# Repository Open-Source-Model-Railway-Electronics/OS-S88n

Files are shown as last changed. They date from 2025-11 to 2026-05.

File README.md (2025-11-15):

# OS-S88n-CS

The OS-S88n modules provide feedback functionality for DCC model railroads using the standardized S88n protocol. These modules allow real-time monitoring of block occupancy and layout events by sending data to your command station or PC-based software.

Models:
    • OS-S88n GND — Standard input module using ground-contact detection  
    • OS-S88n CS — current-sensing module  
    • OS-S88n OPTO — Opto-isolated module for clean, noise-free sensor inputs  

All versions include:
    • Daisy-chainable S88n connectors (RJ-45)  
    • Screw terminals for simple input wiring  
    • Compatibility with all major command stations and software (iTrain, Rocrail, Windigipet, etc.)

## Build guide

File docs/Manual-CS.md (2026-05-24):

> 🌐 &nbsp; [🇬🇧 EN](Manual-EN.md) &nbsp;|&nbsp; [🇩🇪 DE](Manual-DE.md) &nbsp;|&nbsp; [🇫🇷 FR](Manual-FR.md) &nbsp;|&nbsp; [🇳🇱 NL](Manual-NL.md) &nbsp;|&nbsp; [🇪🇸 ES](Manual-ES.md) &nbsp;|&nbsp; [🇮🇹 IT](Manual-IT.md) &nbsp;|&nbsp; [🇵🇱 PL](Manual-PL.md) &nbsp;|&nbsp; 🇨🇿 CS &nbsp;|&nbsp; [🇩🇰 DA](Manual-DA.md) &nbsp;|&nbsp; [🇳🇴 NO](Manual-NO.md) &nbsp;|&nbsp; [🇸🇪 SV](Manual-SV.md) &nbsp;|&nbsp; [🇭🇺 HU](Manual-HU.md) &nbsp;|&nbsp; [🇵🇹 PT](Manual-PT.md)

# Manuál zpětnovazebních modulů OS-S88n

**Podporuje: OS-S88n GND · OS-S88n CS · OS-S88n OPTO**

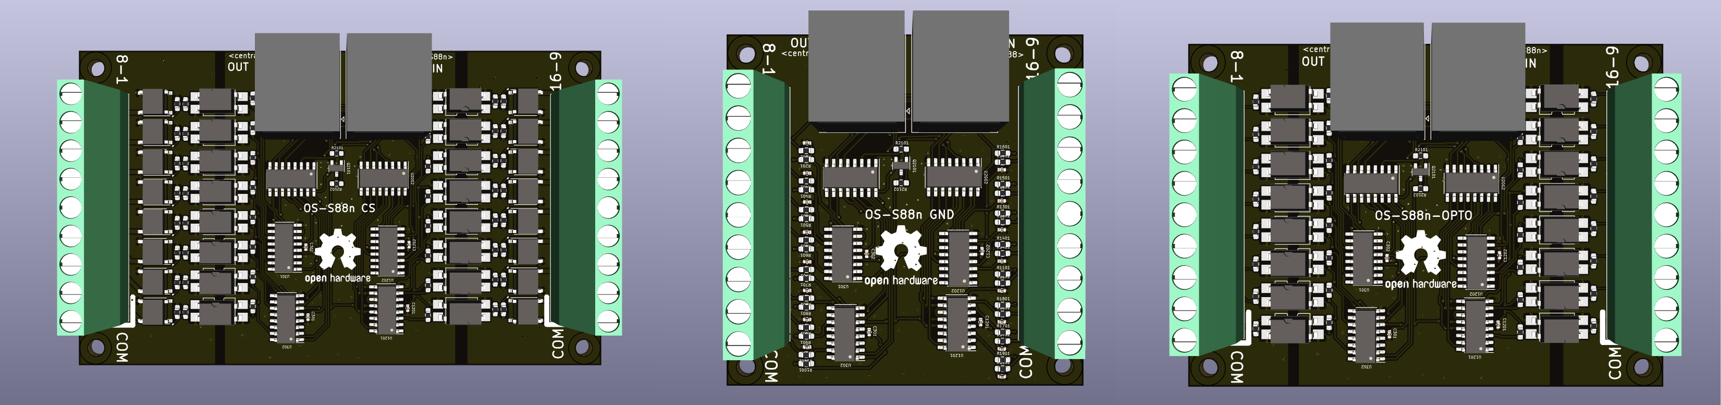
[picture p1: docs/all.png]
Všechny tři varianty modulu OS-S88n


*Zleva doprava: OS-S88n CS, OS-S88n GND, OS-S88n OPTO*

---

## Úvod

Moduly OS-S88n zajišťují zpětnovazební funkci pro DCC modelové železnice pomocí standardizovaného protokolu S88n. Tyto moduly umožňují sledování obsazení bloků a událostí na kolejišti v reálném čase a odesílají data do vaší příkazové stanice nebo počítačového řídicího softwaru.

K dispozici jsou tři varianty pro různé detekční potřeby:

- **OS-S88n GND** — detekce uzemnění, vhodná pro kolejiště s 3 kolejnicemi (ve stylu Märklin)
- **OS-S88n CS** — detekce proudu, vhodná pro digitální kolejiště se 2 i 3 kolejnicemi
- **OS-S88n OPTO** — opticky izolované digitální vstupy pro použití s externími senzory jako jsou IR detektory nebo Hallovy senzory

Všechny varianty obsahují:

- Řetězitelné S88n konektory (RJ-45)
- Šroubové svorky pro všechna připojení senzorů
- Kompatibilita se všemi hlavními příkazovými stanicemi a softwarem (iTrain, Rocrail, Windigipet atd.)

---

## Varianty modulů

### OS-S88n GND — Detekce uzemnění

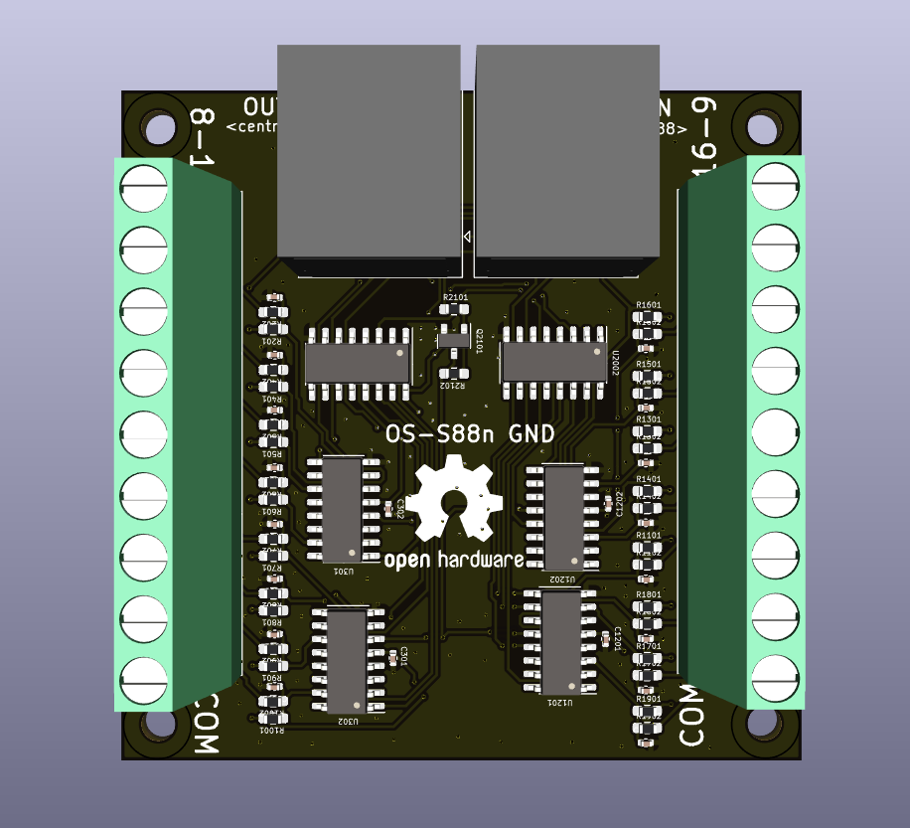
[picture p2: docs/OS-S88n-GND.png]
Deska OS-S88n GND


Modul GND má 16 vstupů, které se aktivují při přivedení vstupu na zem. Kompatibilní senzory a detekční metody zahrnují:

- Reedovy spínače
- Tlačítka
- Kovová kolová soustrojí přemosťující koleje na kolejišti se 3 kolejnicemi (ve stylu Märklin)

⚠️ **Důležité — kolejiště se 3 kolejnicemi:** Při použití modulu GND na kolejišti se 3 kolejnicemi musí vaše příkazová stanice a všechny zesilovače **být** typu se společnou zemí. Pokud vaše příkazová stanice používá H-můstkový výstup, použití modulu GND **poškodí vaši příkazovou stanici**. V takovém případě použijte místo toho variantu OPTO.

---

### OS-S88n CS — Měření proudu

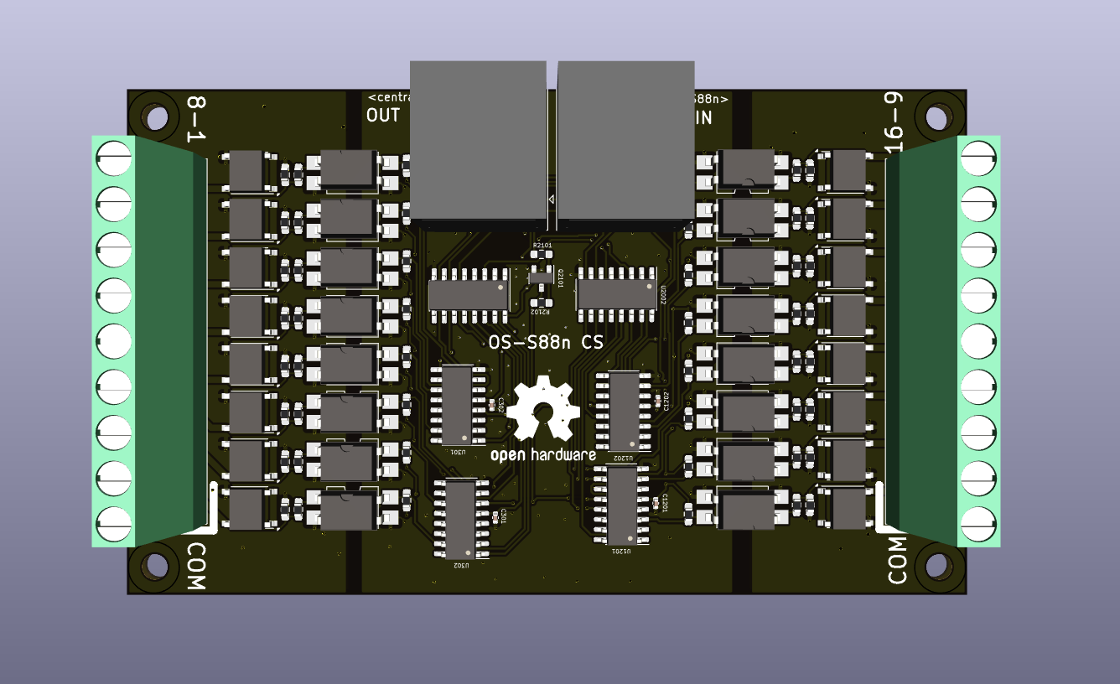
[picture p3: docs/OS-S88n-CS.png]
Deska OS-S88n CS


Modul CS má 16 vstupů, které se aktivují vždy, když prochází proud přes sledovaný kolejový úsek. Jakýkoli kolejový vozidlo odebírající proud spustí detekci, včetně:

- Lokomotiv
- Osvětlených vozů
- Vozů vybavených odporem pro účely detekce

Vhodné pro digitální kolejiště se 2 i 3 kolejnicemi.

---

### OS-S88n OPTO — Opticky izolovaná vstupní detekce

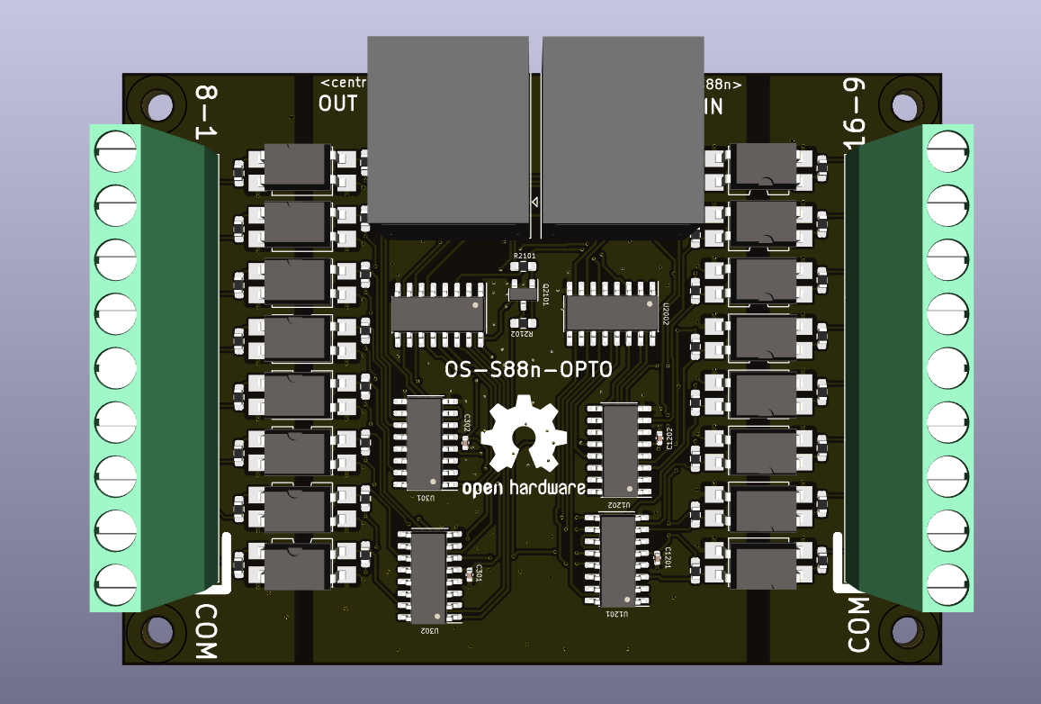
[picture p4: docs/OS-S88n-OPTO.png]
Deska OS-S88n OPTO


Modul OPTO má 16 plně opticky izolovaných digitálních vstupů. Úplná galvanická izolace mezi senzory a S88 sběrnicí činí tuto variantu ideální pro:

- IR detektory
- Hallovy senzory
- Spínače umístěné daleko od modulu
- Prostředí citlivá na rušení
- Kolejiště, kde jsou problémem zemní smyčky nebo elektrické rušení

⚠️ Modul OPTO sám o sobě **nedetekuje** obsazení koleje — vyžaduje externí senzory poskytující logický signál.

---

## Vlastnosti

- Plně kompatibilní s protokolem zpětné vazby S88n
- Konektory RJ-45 pro řetězení modulů
- 16 vstupů na modul
- Řetězení až 31 modulů v jednom řetězci
- Šroubové svorky pro všechna připojení senzorů
- Verze OPTO poskytuje plnou galvanickou izolaci

---

## Připojení modulů

### Napájení a signál

Připojte moduly k vaší příkazové stanici pomocí standardních UTP ethernetových kabelů. **Všechny 8 vodičů musí být zapojeny** — vyhýbejte se levně vyrobeným patch kabelům, které vynechávají vnitřní vodiče.

- Konektor **S88n OUT** → vstup S88n příkazové stanice (nebo vstup IN předchozího modulu)
- Konektor **S88n IN** → následující modul v řetězci (na posledním modulu nechte prázdný)

### Zapojení senzorů

**OS-S88n CS — měření proudu**

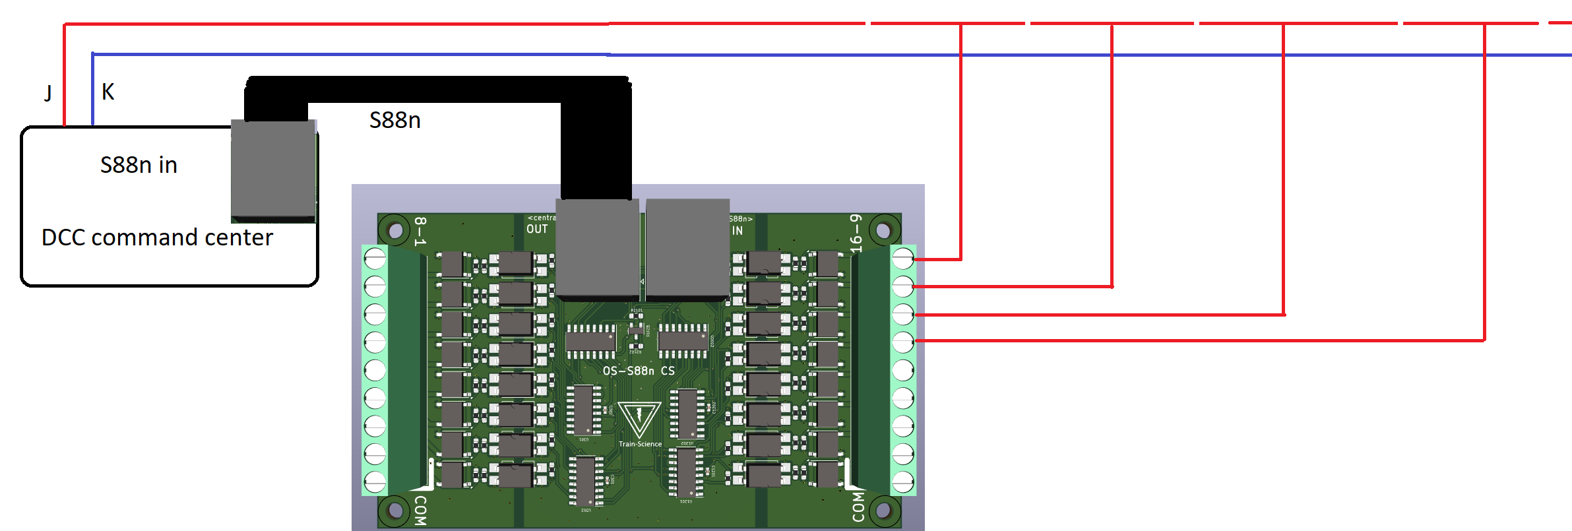
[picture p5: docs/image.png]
Zapojení verze s měřením proudu


Veďte napájecí vodiče koleje pro každý detekční úsek přes vstupy proudového senzoru. Jakýkoli vlak odebírající proud v daném úseku aktivuje odpovídající vstup.

---

**OS-S88n GND — uzemnění**

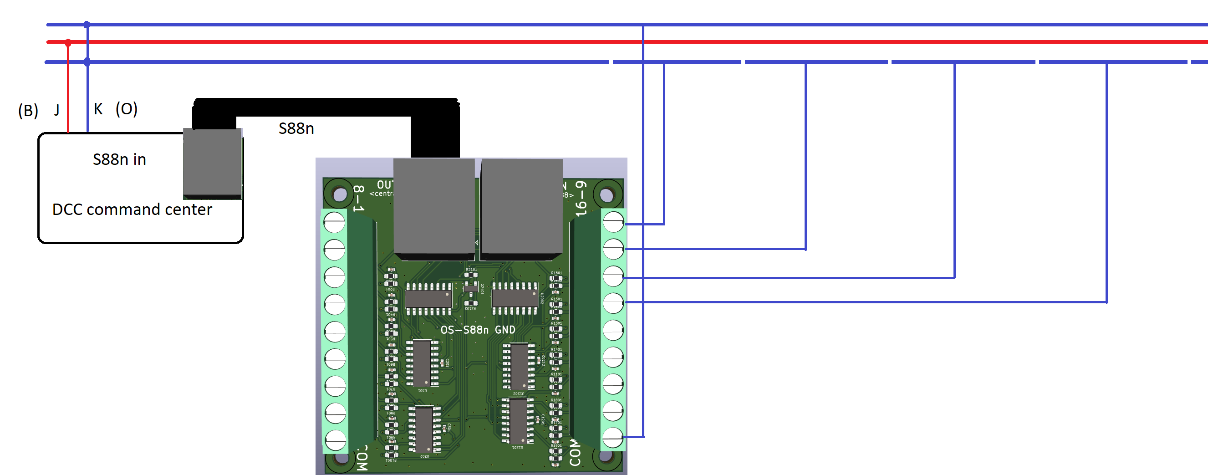
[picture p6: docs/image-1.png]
Zapojení verze GND


Připojte jednu kolejnici (nebo výstup senzoru) ke vstupní svorce a společnou kolejnici ke svorce COM. Kolová soustrojí přemosťující obě kolejnice uzavírají obvod na zem a aktivují vstup.

⚠️ *Při použití verze GND na kolejišti se 3 kolejnicemi je nezbytné, aby příkazová stanice a zesilovače byly typu se společnou zemí. Pokud použijete verzi GND s příkazovou stanicí s H-můstkem, zničíte svou příkazovou stanici. Použijte místo toho variantu OPTO.*

---

**OS-S88n OPTO — opticky izolovaná**

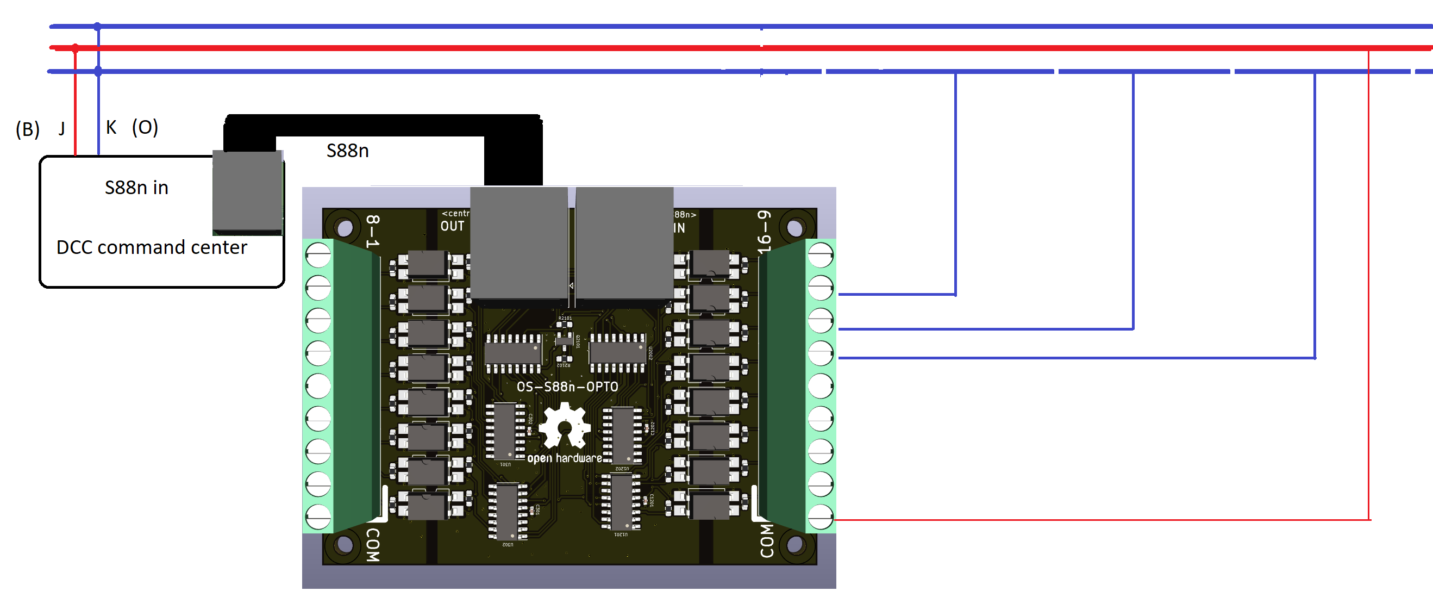
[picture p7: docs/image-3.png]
Zapojení verze OPTO


Připojte signálový výstup vašeho senzoru ke vstupní svorce a uzemnění senzoru ke svorce COM. Vstupní napětí závisí na napájení vašeho senzoru; zkontrolujte potisk na desce pro podporovaný rozsah.

---

**Řetězení více modulů**

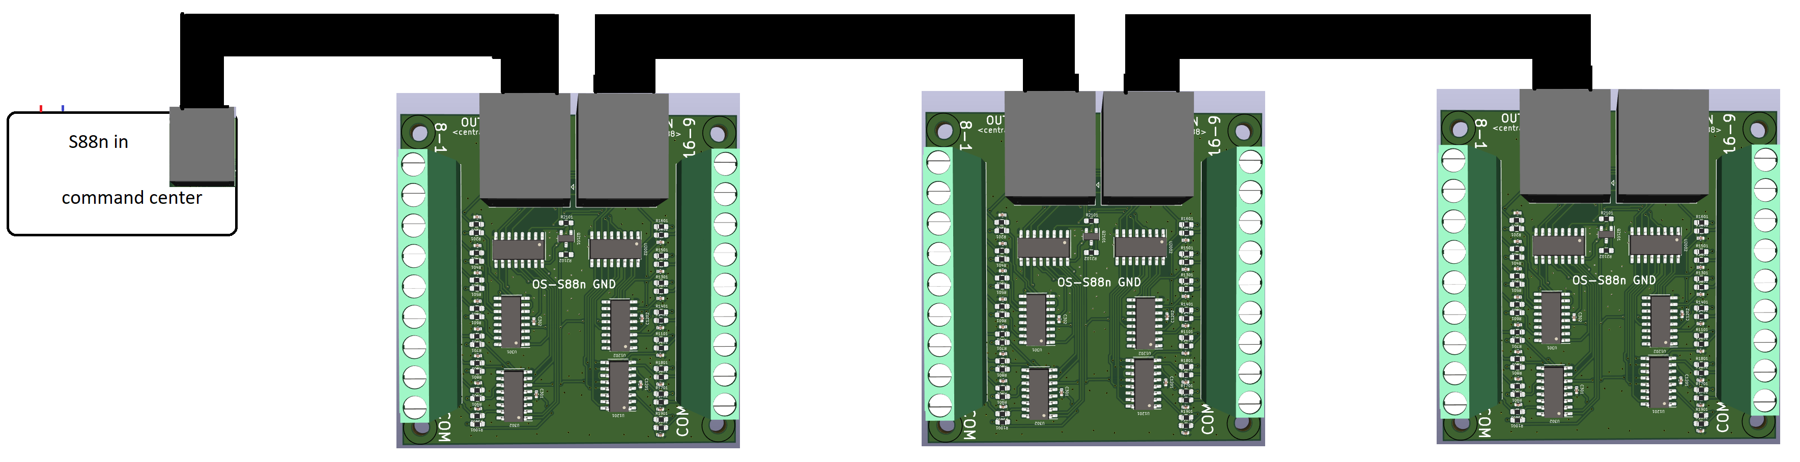
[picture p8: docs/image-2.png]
Řetězení několika modulů OS-S88n


Připojte OUT každého modulu k IN dalšího. OUT prvního modulu jde k příkazové stanici. Konektor IN posledního modulu v řetězci nechte prázdný.

---

## Řešení problémů

**Není přijímána žádná zpětná vazba**
- Zkontrolujte kabeláž RJ-45 a potvrďte, že jsou přítomny všechny 4 páry (8 vodičů)
- Ověřte, že konektor OUT směřuje k příkazové stanici (nikoli IN)
- Ověřte, že rozsah adres modulu ve vašem softwaru odpovídá pozici modulu v řetězci

**Falešné spuštění**
- Verze GND: zkontrolujte zkraty v zapojení nebo rušení mezi detekčními úseky
- Verze CS: zkontrolujte minimální odběr proudu — vozy pouze s LED mohou potřebovat odpor pro spuštění detekce
- Verze OPTO: zkontrolujte napájecí napětí senzoru a polaritu signálu
- Vyhýbejte se ethernetovým kabelům delším než 5 m

**Zpožděná zpětná vazba**
- Snižte interval dotazování v příkazové stanici nebo počítačovém softwaru
- Ověřte správné adresování vstupů ve vašem softwaru

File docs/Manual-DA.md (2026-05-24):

> 🌐 &nbsp; [🇬🇧 EN](Manual-EN.md) &nbsp;|&nbsp; [🇩🇪 DE](Manual-DE.md) &nbsp;|&nbsp; [🇫🇷 FR](Manual-FR.md) &nbsp;|&nbsp; [🇳🇱 NL](Manual-NL.md) &nbsp;|&nbsp; [🇪🇸 ES](Manual-ES.md) &nbsp;|&nbsp; [🇮🇹 IT](Manual-IT.md) &nbsp;|&nbsp; [🇵🇱 PL](Manual-PL.md) &nbsp;|&nbsp; [🇨🇿 CS](Manual-CS.md) &nbsp;|&nbsp; 🇩🇰 DA &nbsp;|&nbsp; [🇳🇴 NO](Manual-NO.md) &nbsp;|&nbsp; [🇸🇪 SV](Manual-SV.md) &nbsp;|&nbsp; [🇭🇺 HU](Manual-HU.md) &nbsp;|&nbsp; [🇵🇹 PT](Manual-PT.md)

# OS-S88n Feedback-moduler Manual

**Understøtter: OS-S88n GND · OS-S88n CS · OS-S88n OPTO**

Alle tre OS-S88n modulvarianter

*Fra venstre mod højre: OS-S88n CS, OS-S88n GND, OS-S88n OPTO*

---

## Introduktion

OS-S88n-modulerne leverer tilbagemeldingsfunktionalitet til DCC-modeljernbaner ved brug af den standardiserede S88n-protokol. Disse moduler muliggør realtidsovervågning af blokokkupering og anlægshændelser, og sender data til din kommandostation eller PC-baserede styresoftware.

Tre varianter er tilgængelige til at imødekomme forskellige detektionsbehov:

- **OS-S88n GND** — jordkontaktdetektion, velegnet til 3-skinne (Märklin-stil) anlæg
- **OS-S88n CS** — strømmålingsdetektion, velegnet til 2-skinne og 3-skinne digitale anlæg
- **OS-S88n OPTO** — optoisolerede digitale indgange, til brug med eksterne sensorer som IR-detektorer eller Hall-sensorer

Alle varianter inkluderer:

- Sammenkoblingsegnet S88n-stik (RJ-45)
- Skrueterminaler til alle sensorforbindelser
- Kompatibilitet med alle større kommandostationer og software (iTrain, Rocrail, Windigipet m.fl.)

---

## Modulvarianter

### OS-S88n GND — Jordkontaktdetektion

OS-S88n GND-kort

GND-modulet har 16 indgange, der aktiveres, når indgangen trækkes til jord. Kompatible sensorer og detektionsmetoder inkluderer:

- Reed-kontakter
- Trykknapper
- Metal-hjulsæt, der bryder begge skinner på et 3-skinne (Märklin-stil) anlæg

⚠️ **Vigtigt — 3-skinne anlæg:** Når GND-modulet bruges på et 3-skinne anlæg, **skal** din kommandostation og alle boostere være af fælles-jord-typen. Hvis din kommandostation bruger et H-bro-output, **vil brug af GND-modulet beskadige din kommandostation**. Brug OPTO-varianten i stedet i det tilfælde.

---

### OS-S88n CS — Strømmåling

OS-S88n CS-kort

CS-modulet har 16 indgange, der aktiveres, hver gang der trækkes strøm gennem en overvåget sporsektion. Ethvert rullende materiel, der trækker strøm, vil udløse detektion, herunder:

- Lokomotiver
- Oplyste vogne
- Godsvogne udstyret med en modstand til detektionsformål

Velegnet til både 2-skinne og 3-skinne digitale anlæg.

---

### OS-S88n OPTO — Optoisoleret indgangsdetektion

OS-S88n OPTO-kort

OPTO-modulet har 16 fuldt optoisolerede digitale indgange. Fuld galvanisk isolation mellem sensorerne og S88-bussen gør denne variant ideel til:

- IR-detektorer
- Hall-sensorer
- Kontakter placeret langt fra modulet
- Støjfølsomme miljøer
- Anlæg, hvor jordslynger eller elektrisk interferens er et problem

⚠️ OPTO-modulet detekterer **ikke** sporokkupering af sig selv — det kræver eksterne sensorer, der leverer et logik-niveau-signal.

---

## Egenskaber

- Fuldt kompatibel med S88n-tilbagemeldingsprotokollen
- RJ-45-stik til sammenkoblingsforbindelse af moduler
- 16 indgange per modul
- Stak op til 31 moduler i en enkelt kæde
- Skrueterminaler til alle sensorforbindelser
- OPTO-versionen leverer fuld galvanisk isolation

---

## Tilslutning af modulerne

### Strøm og signal

Forbind modulerne til din kommandostation ved hjælp af standard UTP Ethernet-kabler. **Alle 8 ledninger skal være forbundet** — undgå billigt fremstillede patchkabler, der udelader interne ledninger.

- **S88n OUT**-stik → kommandostationens S88n-indgang (eller det forrige moduls IN)
- **S88n IN**-stik → næste modul i kæden (lad det stå tomt på det sidste modul)

### Sensorkabeltrækning

**OS-S88n CS — strømmåling**

Kabeltrækning af strømmålingsvarianten

Før sporforsyningsleredningerne til hvert detektionssegment gennem strømmålings-indgangene. Ethvert tog, der trækker strøm i det segment, aktiverer den tilsvarende indgang.

---

**OS-S88n GND — jordkontakt**

Kabeltrækning af GND-varianten

Forbind én skinne (eller sensorudgang) til en indgangsterminal og den fælles skinne til COM-terminalen. Hjulsæt, der bryder begge skinner, fuldfører kredsløbet til jord og udløser indgangen.

⚠️ *Når GND-versionen bruges på et 3-skinne anlæg, er det absolut nødvendigt, at kommandostationen og boosterne er af fælles-jord-typen. Hvis du bruger GND-versionen med en H-bro-kommandostation, vil du ødelægge din kommandostation. Brug OPTO-varianten i stedet.*

---

**OS-S88n OPTO — optoisoleret**

Kabeltrækning af OPTO-varianten

Forbind din sensors signaludgang til indgangsterminalen og sensorjorden til COM-terminalen. Indgangsspændingen afhænger af din sensors forsyning; tjek kortets markeringer for det understøttede område.

---

**Sammenkoblingsforbindelse af flere moduler**

Sammenkoblingsforbindelse af flere OS-S88n-moduler

Forbind OUT fra hvert modul til IN på det næste. Det første moduls OUT går til kommandostationen. Lad IN-stikket på det sidste modul i kæden stå tomt.

---

## Fejlfinding

**Ingen tilbagemelding modtaget**
- Tjek RJ-45-kabling og bekræft, at alle 8 ledere er til stede
- Bekræft, at OUT-stikket peger mod kommandostationen (ikke IN)
- Verificer, at modulets adresseområde i din software svarer til modulets position i kæden

**Falske udløsninger**
- GND-version: tjek for kabelfejl eller interferens mellem detektionssegmenter
- CS-version: tjek minimumstrøkstrøm — vogne med kun LED-belysning kan have brug for en modstand for at udløse detektion
- OPTO-version: tjek sensorforsyningsspænding og signalpolaritet
- Undgå Ethernet-kabler længere end 5 m

**Forsinket tilbagemelding**
- Reducer afsøgningsintervallet i din kommandostation eller PC-software
- Verificer korrekt indgangsadressering i din software

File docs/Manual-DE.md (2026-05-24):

> 🌐 &nbsp; [🇬🇧 EN](Manual-EN.md) &nbsp;|&nbsp; 🇩🇪 DE &nbsp;|&nbsp; [🇫🇷 FR](Manual-FR.md) &nbsp;|&nbsp; [🇳🇱 NL](Manual-NL.md) &nbsp;|&nbsp; [🇪🇸 ES](Manual-ES.md) &nbsp;|&nbsp; [🇮🇹 IT](Manual-IT.md) &nbsp;|&nbsp; [🇵🇱 PL](Manual-PL.md) &nbsp;|&nbsp; [🇨🇿 CS](Manual-CS.md) &nbsp;|&nbsp; [🇩🇰 DA](Manual-DA.md) &nbsp;|&nbsp; [🇳🇴 NO](Manual-NO.md) &nbsp;|&nbsp; [🇸🇪 SV](Manual-SV.md) &nbsp;|&nbsp; [🇭🇺 HU](Manual-HU.md) &nbsp;|&nbsp; [🇵🇹 PT](Manual-PT.md)

# OS-S88n Rückmeldemodule Handbuch

**Unterstützt: OS-S88n GND · OS-S88n CS · OS-S88n OPTO**

Alle drei OS-S88n-Modulvarianten

*Von links nach rechts: OS-S88n CS, OS-S88n GND, OS-S88n OPTO*

---

## Einführung

Die OS-S88n-Module bieten Rückmeldefunktionalität für DCC-Modelleisenbahnen mithilfe des standardisierten S88n-Protokolls. Diese Module ermöglichen die Echtzeitüberwachung der Gleisbesetzung und von Anlagenereignissen und senden Daten an deine Zentrale oder PC-basierte Steuersoftware.

Drei Varianten sind für unterschiedliche Erkennungsanforderungen erhältlich:

- **OS-S88n GND** — Masseberührungs-Erkennung, geeignet für 3-Leiter-Anlagen (Märklin-Stil)
- **OS-S88n CS** — Stromerkennungs-Erkennung, geeignet für 2-Leiter- und 3-Leiter-Digitalanlagen
- **OS-S88n OPTO** — optisch gekoppelte Digitaleingänge, für externe Sensoren wie IR-Detektoren oder Hall-Sensoren

Alle Varianten beinhalten:

- Verkettbare S88n-Stecker (RJ-45)
- Schraubklemmen für alle Sensoranschlüsse
- Kompatibilität mit allen wichtigen Zentralen und Software (iTrain, Rocrail, Windigipet, usw.)

---

## Modulvarianten

### OS-S88n GND — Masseberührungs-Erkennung

OS-S88n GND Platine

Das GND-Modul hat 16 Eingänge, die auslösen, wenn der Eingang auf Masse gezogen wird. Kompatible Sensoren und Erkennungsmethoden umfassen:

- Reedschalter
- Drucktasten
- Metall-Radsätze, die die Schienen einer 3-Leiter-Anlage (Märklin-Stil) überbrücken

⚠️ **Wichtig — 3-Leiter-Anlagen:** Bei Verwendung des GND-Moduls an einer 3-Leiter-Anlage **müssen** Zentrale und alle Booster masseverbundener Bauart sein. Wenn deine Zentrale einen H-Brücken-Ausgang verwendet, **beschädigt** die Verwendung des GND-Moduls deine Zentrale. Verwende in diesem Fall stattdessen die OPTO-Variante.

---

### OS-S88n CS — Stromerkennung

OS-S88n CS Platine

Das CS-Modul hat 16 Eingänge, die aktiviert werden, sobald Strom durch einen überwachten Gleisabschnitt fließt. Jedes Rollmaterial, das Strom zieht, löst eine Erkennung aus, einschließlich:

- Lokomotiven
- Beleuchtete Wagen
- Wagen mit eingebautem Widerstand für Erkennungszwecke

Geeignet für 2-Leiter- und 3-Leiter-Digitalanlagen.

---

### OS-S88n OPTO — Optisch entkoppelte Eingangs-Erkennung

OS-S88n OPTO Platine

Das OPTO-Modul hat 16 vollständig optisch entkoppelte Digitaleingänge. Die vollständige galvanische Trennung zwischen den Sensoren und dem S88-Bus macht diese Variante ideal für:

- IR-Detektoren
- Hall-Sensoren
- Schalter, die weit vom Modul entfernt sind
- Störungsempfindliche Umgebungen
- Anlagen, bei denen Erdschleifen oder elektrische Störungen ein Problem darstellen

⚠️ Das OPTO-Modul erkennt **keine** Gleisbesetzung eigenständig — es benötigt externe Sensoren, die ein Logikpegel-Signal liefern.

---

## Merkmale

- Vollständig kompatibel mit dem S88n-Rückmeldeprotokoll
- RJ-45-Stecker für die Verkettung von Modulen
- 16 Eingänge pro Modul
- Bis zu 31 Module in einer einzelnen Kette stapeln
- Schraubklemmen für alle Sensoranschlüsse
- OPTO-Version bietet vollständige galvanische Trennung

---

## Anschließen der Module

### Strom und Signal

Die Module mithilfe handelsüblicher UTP-Ethernet-Kabel mit der Zentrale verbinden. **Alle 8 Drähte müssen verbunden sein** — billig hergestellte Patchkabel, die interne Drähte weglassen, sind zu vermeiden.

- **S88n OUT**-Stecker → S88n-Eingang der Zentrale (oder IN des vorherigen Moduls)
- **S88n IN**-Stecker → nächstes Modul in der Kette (beim letzten Modul leer lassen)

### Sensorverdrahtung

**OS-S88n CS — Stromerkennung**

Verdrahtung der Stromerkennung-Version

Die Gleiszuleitungsdrähte für jeden Erkennungsabschnitt durch die Stromerkennungseingänge führen. Jeder Zug, der in diesem Abschnitt Strom zieht, aktiviert den entsprechenden Eingang.

---

**OS-S88n GND — Masseberührung**

Verdrahtung der GND-Version

Eine Schiene (oder Sensorausgang) an einen Eingangsklemme anschließen und die gemeinsame Schiene an die COM-Klemme. Radsätze, die beide Schienen überbrücken, schließen den Stromkreis zur Masse und lösen den Eingang aus.

⚠️ *Bei Verwendung der GND-Version an einer 3-Leiter-Anlage ist es unbedingt erforderlich, dass Zentrale und Booster masseverbundener Bauart sind. Bei Verwendung der GND-Version mit einer H-Brücken-Zentrale wird die Zentrale zerstört. Verwende stattdessen die OPTO-Variante.*

---

**OS-S88n OPTO — optisch entkoppelt**

Verdrahtung der OPTO-Version

Den Signalausgang des Sensors an die Eingangsklemme anschließen und die Sensormasse an die COM-Klemme. Die Eingangsspannung hängt von der Versorgung des Sensors ab; die Platinenbeschriftung für den unterstützten Bereich prüfen.

---

**Verketten mehrerer Module**

Verkettung mehrerer OS-S88n-Module

Den OUT jedes Moduls mit dem IN des nächsten verbinden. Der OUT des ersten Moduls geht zur Zentrale. Den IN-Stecker des letzten Moduls in der Kette leer lassen.

---

## Fehlerbehebung

**Keine Rückmeldung erhalten**
- RJ-45-Kabel prüfen und sicherstellen, dass alle 8 Leiter vorhanden sind
- Bestätigen, dass der OUT-Stecker zur Zentrale führt (nicht IN)
- Den Moduladressbereich in der Software mit der Position des Moduls in der Kette abgleichen

**Falsche Auslösungen**
- GND-Version: auf Verdrahtungskurzschlüsse oder Störungen zwischen Erkennungsabschnitten prüfen
- CS-Version: minimalen Stromverbrauch prüfen — reine LED-Wagen benötigen möglicherweise einen Widerstand zur Auslösung der Erkennung
- OPTO-Version: Sensor-Versorgungsspannung und Signalpolarität prüfen
- Ethernet-Kabel länger als 5 m vermeiden

**Verzögerte Rückmeldung**
- Das Abfrageintervall in der Zentrale oder PC-Software verringern
- Korrekte Eingangsadressierung in der Software überprüfen

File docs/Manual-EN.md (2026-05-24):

> 🌐 &nbsp; 🇬🇧 EN &nbsp;|&nbsp; [🇩🇪 DE](Manual-DE.md) &nbsp;|&nbsp; [🇫🇷 FR](Manual-FR.md) &nbsp;|&nbsp; [🇳🇱 NL](Manual-NL.md) &nbsp;|&nbsp; [🇪🇸 ES](Manual-ES.md) &nbsp;|&nbsp; [🇮🇹 IT](Manual-IT.md) &nbsp;|&nbsp; [🇵🇱 PL](Manual-PL.md) &nbsp;|&nbsp; [🇨🇿 CS](Manual-CS.md) &nbsp;|&nbsp; [🇩🇰 DA](Manual-DA.md) &nbsp;|&nbsp; [🇳🇴 NO](Manual-NO.md) &nbsp;|&nbsp; [🇸🇪 SV](Manual-SV.md) &nbsp;|&nbsp; [🇭🇺 HU](Manual-HU.md) &nbsp;|&nbsp; [🇵🇹 PT](Manual-PT.md)

# OS-S88n Feedback Modules Manual

**Supports: OS-S88n GND · OS-S88n CS · OS-S88n OPTO**

All three OS-S88n module variants

*Left to right: OS-S88n CS, OS-S88n GND, OS-S88n OPTO*

---

## Introduction

The OS-S88n modules provide feedback functionality for DCC model railroads using the standardized S88n protocol. These modules allow real-time monitoring of block occupancy and layout events, sending data to your command station or PC-based control software.

Three variants are available to suit different detection needs:

- **OS-S88n GND** — ground-contact detection, suitable for 3-rail (Märklin-style) layouts
- **OS-S88n CS** — current-sensing detection, suitable for 2-rail and 3-rail digital layouts
- **OS-S88n OPTO** — opto-isolated digital inputs, for use with external sensors such as IR detectors or Hall sensors

All variants include:

- Daisy-chainable S88n connectors (RJ-45)
- Screw terminals for all sensor connections
- Compatibility with all major command stations and software (iTrain, Rocrail, Windigipet, etc.)

---

## Module Variants

### OS-S88n GND — Ground Contact Detection

OS-S88n GND board

The GND module has 16 inputs that trigger when the input is pulled to ground. Compatible sensors and detection methods include:

- Reed switches
- Push buttons
- Metal wheelsets bridging the rails on a 3-rail (Märklin-style) layout

⚠️ **Important — 3-rail layouts:** When using the GND module on a 3-rail layout, your command station and all boosters **must** be common-ground type. If your command station uses an H-bridge output, using the GND module **will damage your command station**. Use the OPTO variant instead in that case.

---

### OS-S88n CS — Current Sensing

OS-S88n CS board

The CS module has 16 inputs that activate whenever current is drawn through a monitored track section. Any rolling stock that draws current will trigger detection, including:

- Locomotives
- Lighted coaches
- Wagons fitted with a resistor for detection purposes

Suitable for both 2-rail and 3-rail digital layouts.

---

### OS-S88n OPTO — Opto-Isolated Input Detection

OS-S88n OPTO board

The OPTO module has 16 fully opto-isolated digital inputs. Full galvanic isolation between the sensors and the S88 bus makes this variant ideal for:

- IR detectors
- Hall sensors
- Switches located far from the module
- Noise-sensitive environments
- Layouts where ground loops or electrical interference are a concern

⚠️ The OPTO module does **not** detect track occupancy by itself — it requires external sensors that provide a logic-level signal.

---

## Features

- Fully compatible with the S88n feedback protocol
- RJ-45 connectors for daisy-chaining modules
- 16 inputs per module
- Stack up to 31 modules in a single chain
- Screw terminals for all sensor connections
- OPTO version provides full galvanic isolation

---

## Connecting the Modules

### Power and Signal

Connect the modules to your command station using standard UTP Ethernet cables. **All 8 wires must be connected** — avoid cheaply made patch cables that omit internal wires.

- **S88n OUT** connector → command station S88n input (or the previous module's IN)
- **S88n IN** connector → next module in the chain (leave empty on the last module)

### Sensor Wiring

**OS-S88n CS — current sensing**

Wiring of the Current Sense version

Route the track feed wires for each detection section through the current sensor inputs. Any train drawing current in that section activates the corresponding input.

---

**OS-S88n GND — ground contact**

Wiring of the GND version

Connect one rail (or sensor output) to an input terminal and the common rail to the COM terminal. Wheelsets bridging both rails complete the circuit to ground and trigger the input.

⚠️ *When using the GND version on a 3-rail layout, it is imperative that the command station and boosters are common-ground type. If you use the GND version with an H-bridge command station, you will destroy your command station. Use the OPTO variant instead.*

---

**OS-S88n OPTO — opto-isolated**

Wiring of the OPTO version

Connect your sensor's signal output to the input terminal and the sensor ground to the COM terminal. The input voltage depends on your sensor's supply; check the board markings for the supported range.

---

**Daisy-chaining multiple modules**

Daisy-chaining several OS-S88n modules

Connect the OUT of each module to the IN of the next. The first module's OUT goes to the command station. Leave the IN connector of the last module in the chain empty.

---

## Troubleshooting

**No feedback received**
- Check RJ-45 cabling and confirm all 8 conductors are present
- Confirm the OUT connector goes toward the command station (not IN)
- Verify the module address range in your software matches the module's position in the chain

**False triggers**
- GND version: check for wiring shorts or interference between detection sections
- CS version: check minimum current draw — LED-only wagons may need a resistor to trigger detection
- OPTO version: check sensor supply voltage and signal polarity
- Avoid Ethernet cables longer than 5 m

**Delayed feedback**
- Reduce the polling interval in your command station or PC software
- Verify correct input addressing in your software

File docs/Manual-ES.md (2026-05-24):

> 🌐 &nbsp; [🇬🇧 EN](Manual-EN.md) &nbsp;|&nbsp; [🇩🇪 DE](Manual-DE.md) &nbsp;|&nbsp; [🇫🇷 FR](Manual-FR.md) &nbsp;|&nbsp; [🇳🇱 NL](Manual-NL.md) &nbsp;|&nbsp; 🇪🇸 ES &nbsp;|&nbsp; [🇮🇹 IT](Manual-IT.md) &nbsp;|&nbsp; [🇵🇱 PL](Manual-PL.md) &nbsp;|&nbsp; [🇨🇿 CS](Manual-CS.md) &nbsp;|&nbsp; [🇩🇰 DA](Manual-DA.md) &nbsp;|&nbsp; [🇳🇴 NO](Manual-NO.md) &nbsp;|&nbsp; [🇸🇪 SV](Manual-SV.md) &nbsp;|&nbsp; [🇭🇺 HU](Manual-HU.md) &nbsp;|&nbsp; [🇵🇹 PT](Manual-PT.md)

# Manual de los Módulos de Retroalimentación OS-S88n

**Compatible con: OS-S88n GND · OS-S88n CS · OS-S88n OPTO**

Las tres variantes del módulo OS-S88n

*De izquierda a derecha: OS-S88n CS, OS-S88n GND, OS-S88n OPTO*

---

## Introducción

Los módulos OS-S88n proporcionan funcionalidad de retroalimentación para maquetas de ferrocarril DCC mediante el protocolo S88n estandarizado. Estos módulos permiten la monitorización en tiempo real de la ocupación de bloques y los eventos de la maqueta, enviando datos a la central de mando o al software de control basado en PC.

Hay tres variantes disponibles para diferentes necesidades de detección:

- **OS-S88n GND** — detección por contacto a masa, adecuada para maquetas de 3 carriles (estilo Märklin)
- **OS-S88n CS** — detección por sensor de corriente, adecuada para maquetas digitales de 2 y 3 carriles
- **OS-S88n OPTO** — entradas digitales optoacopladas, para uso con sensores externos como detectores IR o sensores Hall

Todas las variantes incluyen:

- Conectores S88n encadenables (RJ-45)
- Bornes de tornillo para todas las conexiones de sensores
- Compatibilidad con todas las principales centrales de mando y programas (iTrain, Rocrail, Windigipet, etc.)

---

## Variantes del Módulo

### OS-S88n GND — Detección por Contacto a Masa

Placa OS-S88n GND

El módulo GND tiene 16 entradas que se activan cuando la entrada se lleva a masa. Los sensores y métodos de detección compatibles incluyen:

- Contactos reed
- Pulsadores
- Ruedas metálicas que puentean los carriles en una maqueta de 3 carriles (estilo Märklin)

⚠️ **Importante — maquetas de 3 carriles:** Al usar el módulo GND en una maqueta de 3 carriles, la central de mando y todos los amplificadores **deben** ser del tipo de masa común. Si su central usa una salida en puente H, usar el módulo GND **dañará su central**. En ese caso utilice la variante OPTO.

---

### OS-S88n CS — Sensor de Corriente

Placa OS-S88n CS

El módulo CS tiene 16 entradas que se activan cuando hay circulación de corriente a través de una sección de vía monitorizada. Cualquier material rodante que consuma corriente activará la detección, incluyendo:

- Locomotoras
- Coches iluminados
- Vagones equipados con una resistencia para fines de detección

Adecuado tanto para maquetas digitales de 2 como de 3 carriles.

---

### OS-S88n OPTO — Detección de Entradas Optoacopladas

Placa OS-S88n OPTO

El módulo OPTO tiene 16 entradas digitales completamente optoacopladas. El aislamiento galvánico total entre los sensores y el bus S88 hace que esta variante sea ideal para:

- Detectores IR
- Sensores Hall
- Interruptores ubicados lejos del módulo
- Entornos sensibles al ruido eléctrico
- Maquetas donde los bucles de masa o las interferencias eléctricas son una preocupación

⚠️ El módulo OPTO **no** detecta la ocupación de vía por sí solo — requiere sensores externos que proporcionen una señal de nivel lógico.

---

## Características

- Totalmente compatible con el protocolo de retroalimentación S88n
- Conectores RJ-45 para encadenamiento de módulos
- 16 entradas por módulo
- Encadene hasta 31 módulos en una sola cadena
- Bornes de tornillo para todas las conexiones de sensores
- La versión OPTO proporciona aislamiento galvánico completo

---

## Conexión de los Módulos

### Alimentación y Señal

Conecte los módulos a su central mediante cables Ethernet UTP estándar. **Deben conectarse los 8 conductores** — evite cables de conexión de baja calidad que omitan conductores internos.

- Conector **S88n OUT** → entrada S88n de la central (o el IN del módulo anterior)
- Conector **S88n IN** → siguiente módulo de la cadena (déjelo vacío en el último módulo)

### Cableado de Sensores

**OS-S88n CS — sensor de corriente**

Cableado de la versión de sensor de corriente

Encamine los cables de alimentación de vía de cada sección de detección a través de las entradas del sensor de corriente. Cualquier tren que consuma corriente en esa sección activa la entrada correspondiente.

---

**OS-S88n GND — contacto a masa**

Cableado de la versión GND

Conecte un carril (o la salida del sensor) a un borne de entrada y el carril común al borne COM. Las ruedas que puentean ambos carriles completan el circuito a masa y activan la entrada.

⚠️ *Al usar la versión GND en una maqueta de 3 carriles, es imprescindible que la central y los amplificadores sean del tipo de masa común. Si usa la versión GND con una central de puente H, destruirá su central. Utilice la variante OPTO en su lugar.*

---

**OS-S88n OPTO — optoacoplado**

Cableado de la versión OPTO

Conecte la salida de señal del sensor al borne de entrada y la masa del sensor al borne COM. La tensión de entrada depende de la alimentación de su sensor; compruebe las marcas de la placa para conocer el rango admitido.

---

**Encadenamiento de múltiples módulos**

Encadenamiento de varios módulos OS-S88n

Conecte el OUT de cada módulo al IN del siguiente. El OUT del primer módulo va a la central. Deje vacío el conector IN del último módulo de la cadena.

---

## Resolución de Problemas

**No se recibe retroalimentación**
- Compruebe el cableado RJ-45 y confirme que los 8 conductores están presentes
- Compruebe que el conector OUT apunta hacia la central (no el IN)
- Verifique que el rango de direcciones del módulo en su software coincide con la posición del módulo en la cadena

**Activaciones falsas**
- Versión GND: compruebe cortocircuitos en el cableado o interferencias entre secciones de detección
- Versión CS: compruebe la corriente mínima consumida — los vagones con solo LED pueden necesitar una resistencia para activar la detección
- Versión OPTO: compruebe la tensión de alimentación del sensor y la polaridad de la señal
- Evite cables Ethernet de más de 5 m

**Retroalimentación retrasada**
- Reduzca el intervalo de sondeo en su central o software de PC
- Verifique el direccionamiento de entradas correcto en su software

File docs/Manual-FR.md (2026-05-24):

> 🌐 &nbsp; [🇬🇧 EN](Manual-EN.md) &nbsp;|&nbsp; [🇩🇪 DE](Manual-DE.md) &nbsp;|&nbsp; 🇫🇷 FR &nbsp;|&nbsp; [🇳🇱 NL](Manual-NL.md) &nbsp;|&nbsp; [🇪🇸 ES](Manual-ES.md) &nbsp;|&nbsp; [🇮🇹 IT](Manual-IT.md) &nbsp;|&nbsp; [🇵🇱 PL](Manual-PL.md) &nbsp;|&nbsp; [🇨🇿 CS](Manual-CS.md) &nbsp;|&nbsp; [🇩🇰 DA](Manual-DA.md) &nbsp;|&nbsp; [🇳🇴 NO](Manual-NO.md) &nbsp;|&nbsp; [🇸🇪 SV](Manual-SV.md) &nbsp;|&nbsp; [🇭🇺 HU](Manual-HU.md) &nbsp;|&nbsp; [🇵🇹 PT](Manual-PT.md)

# Manuel des modules de retour OS-S88n

**Prend en charge : OS-S88n GND · OS-S88n CS · OS-S88n OPTO**

Les trois variantes du module OS-S88n

*De gauche à droite : OS-S88n CS, OS-S88n GND, OS-S88n OPTO*

---

## Introduction

Les modules OS-S88n fournissent des fonctionnalités de retour d'information pour les réseaux ferroviaires miniatures DCC en utilisant le protocole standardisé S88n. Ces modules permettent la surveillance en temps réel de l'occupation des cantons et des événements du réseau, en transmettant les données à votre centrale ou logiciel de commande sur PC.

Trois variantes sont disponibles pour répondre à différents besoins de détection :

- **OS-S88n GND** — détection par contact à la masse, adaptée aux réseaux à 3 rails (style Märklin)
- **OS-S88n CS** — détection par mesure de courant, adaptée aux réseaux numériques 2 et 3 rails
- **OS-S88n OPTO** — entrées numériques à isolation optique, pour une utilisation avec des capteurs externes tels que des détecteurs IR ou des capteurs à effet Hall

Toutes les variantes incluent :

- Connecteurs S88n enchaînables (RJ-45)
- Borniers à vis pour toutes les connexions de capteurs
- Compatibilité avec toutes les principales centrales et logiciels (iTrain, Rocrail, Windigipet, etc.)

---

## Variantes du module

### OS-S88n GND — Détection par contact à la masse

Carte OS-S88n GND

Le module GND dispose de 16 entrées qui se déclenchent lorsque l'entrée est amenée à la masse. Les capteurs et méthodes de détection compatibles comprennent :

- Contacts reed
- Boutons poussoirs
- Essieux métalliques pontant les rails sur un réseau à 3 rails (style Märklin)

⚠️ **Important — réseaux à 3 rails :** Lors de l'utilisation du module GND sur un réseau à 3 rails, votre centrale et tous les boosters **doivent** être du type à masse commune. Si votre centrale utilise une sortie en pont H, utiliser le module GND **endommagera votre centrale**. Utilisez à la place la variante OPTO dans ce cas.

---

### OS-S88n CS — Mesure de courant

Carte OS-S88n CS

Le module CS dispose de 16 entrées qui s'activent dès qu'un courant est consommé dans une section de voie surveillée. Tout matériel roulant consommant du courant déclenchera la détection, notamment :

- Les locomotives
- Les voitures éclairées
- Les wagons équipés d'une résistance à des fins de détection

Adapté aux réseaux numériques 2 et 3 rails.

---

### OS-S88n OPTO — Détection par entrée à isolation optique

Carte OS-S88n OPTO

Le module OPTO dispose de 16 entrées numériques entièrement à isolation optique. L'isolation galvanique complète entre les capteurs et le bus S88 rend cette variante idéale pour :

- Les détecteurs IR
- Les capteurs à effet Hall
- Les interrupteurs situés loin du module
- Les environnements sensibles aux perturbations
- Les réseaux où les boucles de masse ou les interférences électriques sont une préoccupation

⚠️ Le module OPTO ne **détecte pas** l'occupation de la voie par lui-même — il nécessite des capteurs externes fournissant un signal de niveau logique.

---

## Caractéristiques

- Entièrement compatible avec le protocole de retour S88n
- Connecteurs RJ-45 pour l'enchaînement des modules
- 16 entrées par module
- Enchaînement jusqu'à 31 modules dans une seule chaîne
- Borniers à vis pour toutes les connexions de capteurs
- La version OPTO offre une isolation galvanique complète

---

## Connexion des modules

### Alimentation et signal

Connectez les modules à votre centrale à l'aide de câbles Ethernet UTP standard. **Les 8 fils doivent être connectés** — évitez les câbles de brassage bon marché qui omettent des fils internes.

- Connecteur **S88n OUT** → entrée S88n de la centrale (ou l'IN du module précédent)
- Connecteur **S88n IN** → module suivant dans la chaîne (laisser vide sur le dernier module)

### Câblage des capteurs

**OS-S88n CS — mesure de courant**

Câblage de la version à mesure de courant

Faites passer les fils d'alimentation de voie pour chaque section de détection à travers les entrées de capteur de courant. Tout train consommant du courant dans cette section active l'entrée correspondante.

---

**OS-S88n GND — contact à la masse**

Câblage de la version GND

Connectez un rail (ou la sortie du capteur) à une borne d'entrée et le rail commun à la borne COM. Les essieux pontant les deux rails complètent le circuit vers la masse et déclenchent l'entrée.

⚠️ *Lors de l'utilisation de la version GND sur un réseau à 3 rails, il est impératif que la centrale et les boosters soient du type à masse commune. Si vous utilisez la version GND avec une centrale à pont H, vous détruirez votre centrale. Utilisez plutôt la variante OPTO.*

---

**OS-S88n OPTO — à isolation optique**

Câblage de la version OPTO

Connectez la sortie de signal de votre capteur à la borne d'entrée et la masse du capteur à la borne COM. La tension d'entrée dépend de l'alimentation de votre capteur ; vérifiez les marquages de la carte pour la plage prise en charge.

---

**Enchaînement de plusieurs modules**

Enchaînement de plusieurs modules OS-S88n

Connectez la sortie OUT de chaque module à l'entrée IN du suivant. La sortie OUT du premier module va vers la centrale. Laissez le connecteur IN du dernier module de la chaîne vide.

---

## Dépannage

**Aucun retour reçu**
- Vérifiez le câblage RJ-45 et confirmez que les 8 conducteurs sont présents
- Confirmez que le connecteur OUT est orienté vers la centrale (et non l'IN)
- Vérifiez que la plage d'adresses du module dans votre logiciel correspond à la position du module dans la chaîne

**Déclenchements intempestifs**
- Version GND : vérifiez les courts-circuits de câblage ou les interférences entre les sections de détection
- Version CS : vérifiez la consommation de courant minimale — les wagons à LED uniquement peuvent nécessiter une résistance pour déclencher la détection
- Version OPTO : vérifiez la tension d'alimentation du capteur et la polarité du signal
- Évitez les câbles Ethernet de plus de 5 m

**Retour différé**
- Réduisez l'intervalle d'interrogation dans votre centrale ou logiciel PC
- Vérifiez l'adressage d'entrée correct dans votre logiciel

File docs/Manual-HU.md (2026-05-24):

> 🌐 &nbsp; [🇬🇧 EN](Manual-EN.md) &nbsp;|&nbsp; [🇩🇪 DE](Manual-DE.md) &nbsp;|&nbsp; [🇫🇷 FR](Manual-FR.md) &nbsp;|&nbsp; [🇳🇱 NL](Manual-NL.md) &nbsp;|&nbsp; [🇪🇸 ES](Manual-ES.md) &nbsp;|&nbsp; [🇮🇹 IT](Manual-IT.md) &nbsp;|&nbsp; [🇵🇱 PL](Manual-PL.md) &nbsp;|&nbsp; [🇨🇿 CS](Manual-CS.md) &nbsp;|&nbsp; [🇩🇰 DA](Manual-DA.md) &nbsp;|&nbsp; [🇳🇴 NO](Manual-NO.md) &nbsp;|&nbsp; [🇸🇪 SV](Manual-SV.md) &nbsp;|&nbsp; 🇭🇺 HU &nbsp;|&nbsp; [🇵🇹 PT](Manual-PT.md)

# OS-S88n Visszajelző Modulok Kézikönyve

**Támogatja: OS-S88n GND · OS-S88n CS · OS-S88n OPTO**

Mindhárom OS-S88n modul változat

*Balról jobbra: OS-S88n CS, OS-S88n GND, OS-S88n OPTO*

---

## Bevezetés

Az OS-S88n modulok visszajelzési funkciót biztosítanak DCC modellvasutakhoz a szabványos S88n protokoll segítségével. Ezek a modulok valós idejű blokk-foglaltsági és pályaesemény-figyelést tesznek lehetővé, az adatokat a parancsvezérlőhöz vagy PC-alapú vezérlő szoftverhez továbbítva.

Három változat érhető el a különböző érzékelési igényekhez:

- **OS-S88n GND** — földkontaktusos érzékelés, 3 sínes (Märklin-stílusú) pályákhoz alkalmas
- **OS-S88n CS** — áramfigyeléses érzékelés, 2 sínes és 3 sínes digitális pályákhoz alkalmas
- **OS-S88n OPTO** — optoizolált digitális bemenetek, külső érzékelőkkel, pl. IR detektorokkal vagy Hall-érzékelőkkel való használatra

Minden változat tartalmaz:

- Láncolható S88n csatlakozókat (RJ-45)
- Csavartalpas csatlakozókat az összes érzékelő bekötéséhez
- Kompatibilitást az összes főbb parancsvezérlővel és szoftverrel (iTrain, Rocrail, Windigipet stb.)

---

## Modul Változatok

### OS-S88n GND — Földkontaktusos Érzékelés

OS-S88n GND lap

A GND modul 16 bemenete akkor aktiválódik, ha a bemenetet földre húzzák. Kompatibilis érzékelők és érzékelési módszerek:

- Nádrelék
- Nyomógombok
- Fémkerék-párok, amelyek a 3 sínes (Märklin-stílusú) pályán áthidalják a síneket

⚠️ **Fontos — 3 sínes pályák:** Ha a GND modult 3 sínes pályán használod, a parancsvezérlőnek és az összes erősítőnek **közös földelésű** típusnak kell lennie. Ha a parancsvezérlő H-híd kimenetet használ, a GND modul alkalmazása **megrongálja a parancsvezérlőt**. Ez esetben inkább az OPTO változatot használd.

---

### OS-S88n CS — Áramfigyelés

OS-S88n CS lap

A CS modul 16 bemenete akkor aktiválódik, amikor áram folyik át a figyelt pályaszakaszon. Minden gurulóállomány, amely áramot vesz fel, kiváltja az érzékelést, beleértve:

- Mozdonyokat
- Megvilágított kocsikat
- Érzékelési célból ellenállással felszerelt vagonokat

Alkalmas mind 2 sínes, mind 3 sínes digitális pályákhoz.

---

### OS-S88n OPTO — Optoizolált Bemeneti Érzékelés

OS-S88n OPTO lap

Az OPTO modul 16 teljesen optoizolált digitális bemenettel rendelkezik. Az érzékelők és az S88 busz közötti teljes galvanikus szigetelés ezt a változatot ideálissá teszi:

- IR detektorokhoz
- Hall-érzékelőkhöz
- A modultól messze elhelyezett kapcsolókhoz
- Zajérzékeny környezetekhez
- Olyan pályákhoz, ahol a földhurok vagy elektromos zavar problémát okoz

⚠️ Az OPTO modul önállóan **nem** érzékeli a sínfoglaltságot — logikai szintű jelet adó külső érzékelőkre van szükség.

---

## Jellemzők

- Teljes kompatibilitás az S88n visszajelző protokollal
- RJ-45 csatlakozók a modulok láncolásához
- 16 bemenet modulonként
- Legfeljebb 31 modul fűzhető egy láncba
- Csavartalpas csatlakozók az összes érzékelő bekötéséhez
- Az OPTO változat teljes galvanikus szigetelést biztosít

---

## A Modulok Csatlakoztatása

### Tápellátás és Jel

Csatlakoztasd a modulokat a parancsvezérlőhöz szabványos UTP Ethernet kábelekkel. **Mind a 8 érnek csatlakoztatva kell lennie** — kerüld az olcsó patch kábeleket, amelyekből hiányoznak a belső erek.

- **S88n OUT** csatlakozó → parancsvezérlő S88n bemenete (vagy az előző modul IN-je)
- **S88n IN** csatlakozó → következő modul a láncban (a lánc utolsó modulján üresen hagyni)

### Érzékelő Bekötése

**OS-S88n CS — áramfigyelés**

Az áramfigyelő változat bekötése

Vezésd át az egyes érzékelési szakaszok sínáramvezékeit az áramfigyelő bemeneteken. Minden olyan jármű, amely áramot vesz fel az adott szakaszon, aktiválja a megfelelő bemenetet.

---

**OS-S88n GND — földkontaktus**

A GND változat bekötése

Csatlakoztass egy sínt (vagy érzékelő kimenetet) egy bemeneti csatlakozóhoz, a közös sínt pedig a COM csatlakozóhoz. Az egymást érintő kerékpárok mindkét sínen áthidalják az áramkört földre és kiváltják a bemenetet.

⚠️ *Ha a GND változatot 3 sínes pályán használod, elengedhetetlen, hogy a parancsvezérlő és az erősítők közös földelésű típusúak legyenek. Ha a GND változatot H-híd parancsvezérlővel használod, tönkreteszed a parancsvezérlőt. Helyette használd az OPTO változatot.*

---

**OS-S88n OPTO — optoizolált**

Az OPTO változat bekötése

Csatlakoztasd az érzékelő jelkimenetét a bemeneti csatlakozóhoz, az érzékelő földjét pedig a COM csatlakozóhoz. A bemeneti feszültség az érzékelő tápellátásától függ; ellenőrizd a lap jelöléseit a támogatott tartományhoz.

---

**Több modul láncolása**

Több OS-S88n modul láncolása

Csatlakoztasd minden modul OUT-ját a következő modul IN-jéhez. Az első modul OUT-ja megy a parancsvezérlőhöz. A lánc utolsó moduljának IN csatlakozóját hagyd üresen.

---

## Hibaelhárítás

**Nem érkezik visszajelzés**
- Ellenőrizd az RJ-45 kábelezést, és győződj meg arról, hogy mind a 8 ér jelen van
- Ellenőrizd, hogy az OUT csatlakozó a parancsvezérlő felé mutat (nem az IN)
- Ellenőrizd, hogy a szoftverben beállított modulcím-tartomány megfelel a modul helyzetének a láncban

**Hamis aktiválódások**
- GND változat: ellenőrizd a rövidzárlatokat vagy zavarokat az érzékelési szakaszok között
- CS változat: ellenőrizd a minimális áramfelvételt — csak LED-es vagonokhoz ellenállás szükséges a kiváltáshoz
- OPTO változat: ellenőrizd az érzékelő tápfeszültségét és a jel polaritását
- Kerüld az 5 m-nél hosszabb Ethernet kábeleket

**Késleltetett visszajelzés**
- Csökkentsd a lekérdezési intervallumot a parancsvezérlőn vagy a PC szoftverben
- Ellenőrizd a helyes bemeneti címzést a szoftverben

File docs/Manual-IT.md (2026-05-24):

> 🌐 &nbsp; [🇬🇧 EN](Manual-EN.md) &nbsp;|&nbsp; [🇩🇪 DE](Manual-DE.md) &nbsp;|&nbsp; [🇫🇷 FR](Manual-FR.md) &nbsp;|&nbsp; [🇳🇱 NL](Manual-NL.md) &nbsp;|&nbsp; [🇪🇸 ES](Manual-ES.md) &nbsp;|&nbsp; 🇮🇹 IT &nbsp;|&nbsp; [🇵🇱 PL](Manual-PL.md) &nbsp;|&nbsp; [🇨🇿 CS](Manual-CS.md) &nbsp;|&nbsp; [🇩🇰 DA](Manual-DA.md) &nbsp;|&nbsp; [🇳🇴 NO](Manual-NO.md) &nbsp;|&nbsp; [🇸🇪 SV](Manual-SV.md) &nbsp;|&nbsp; [🇭🇺 HU](Manual-HU.md) &nbsp;|&nbsp; [🇵🇹 PT](Manual-PT.md)

# Manuale Moduli di Feedback OS-S88n

**Supporta: OS-S88n GND · OS-S88n CS · OS-S88n OPTO**

Tutte e tre le varianti del modulo OS-S88n

*Da sinistra a destra: OS-S88n CS, OS-S88n GND, OS-S88n OPTO*

---

## Introduzione

I moduli OS-S88n forniscono funzionalità di feedback per plastici ferroviari DCC utilizzando il protocollo S88n standardizzato. Questi moduli consentono il monitoraggio in tempo reale dell'occupazione dei blocchi e degli eventi del plastico, inviando i dati alla propria centrale di comando o al software di controllo su PC.

Sono disponibili tre varianti per soddisfare diverse esigenze di rilevamento:

- **OS-S88n GND** — rilevamento a contatto con la massa, adatto per plastici a 3 rotaie (stile Märklin)
- **OS-S88n CS** — rilevamento a sensore di corrente, adatto per plastici digitali a 2 e 3 rotaie
- **OS-S88n OPTO** — ingressi digitali optoisolati, da utilizzare con sensori esterni come rilevatori IR o sensori Hall

Tutte le varianti includono:

- Connettori S88n a cascata (RJ-45)
- Morsetti a vite per tutte le connessioni dei sensori
- Compatibilità con tutte le principali centrali di comando e software (iTrain, Rocrail, Windigipet, ecc.)

---

## Varianti del Modulo

### OS-S88n GND — Rilevamento a Contatto con la Massa

Scheda OS-S88n GND

Il modulo GND dispone di 16 ingressi che si attivano quando l'ingresso viene portato a massa. I sensori e i metodi di rilevamento compatibili includono:

- Contatti Reed
- Pulsanti
- Assili metallici che cortocircuitano le rotaie su un plastico a 3 rotaie (stile Märklin)

⚠️ **Importante — plastici a 3 rotaie:** quando si utilizza il modulo GND su un plastico a 3 rotaie, la propria centrale di comando e tutti i booster **devono** essere del tipo a massa comune. Se la centrale di comando utilizza un'uscita a ponte H, l'utilizzo del modulo GND **danneggerà la centrale**. In tal caso utilizzare invece la variante OPTO.

---

### OS-S88n CS — Sensore di Corrente

Scheda OS-S88n CS

Il modulo CS dispone di 16 ingressi che si attivano ogni volta che viene assorbita corrente attraverso una sezione di binario monitorata. Qualsiasi materiale rotabile che assorbe corrente attiverà il rilevamento, inclusi:

- Locomotive
- Carrozze illuminate
- Vagoni dotati di resistore a scopo di rilevamento

Adatto sia per plastici digitali a 2 che a 3 rotaie.

---

### OS-S88n OPTO — Rilevamento a Ingresso Optoisolato

Scheda OS-S88n OPTO

Il modulo OPTO dispone di 16 ingressi digitali completamente optoisolati. Il pieno isolamento galvanico tra i sensori e il bus S88 rende questa variante ideale per:

- Rilevatori IR
- Sensori Hall
- Interruttori situati lontano dal modulo
- Ambienti sensibili ai disturbi
- Plastici in cui i loop di massa o le interferenze elettriche rappresentano un problema

⚠️ Il modulo OPTO **non** rileva di per sé l'occupazione del binario — richiede sensori esterni che forniscano un segnale a livello logico.

---

## Caratteristiche

- Completamente compatibile con il protocollo di feedback S88n
- Connettori RJ-45 per il collegamento a cascata dei moduli
- 16 ingressi per modulo
- Fino a 31 moduli in una singola catena
- Morsetti a vite per tutte le connessioni dei sensori
- La versione OPTO fornisce pieno isolamento galvanico

---

## Collegamento dei Moduli

### Alimentazione e Segnale

Collegare i moduli alla propria centrale di comando utilizzando cavi Ethernet UTP standard. **Tutti gli 8 fili devono essere collegati** — evitare cavi patch di bassa qualità che omettono alcuni fili interni.

- Connettore **S88n OUT** → ingresso S88n della centrale (o ingresso IN del modulo precedente)
- Connettore **S88n IN** → modulo successivo nella catena (lasciare vuoto sull'ultimo modulo)

### Cablaggio dei Sensori

**OS-S88n CS — sensore di corrente**

Cablaggio della versione a sensore di corrente

Instradare i fili di alimentazione del binario per ciascuna sezione di rilevamento attraverso gli ingressi del sensore di corrente. Qualsiasi treno che assorba corrente in quella sezione attiva l'ingresso corrispondente.

---

**OS-S88n GND — contatto con la massa**

Cablaggio della versione GND

Collegare una rotaia (o l'uscita del sensore) a un morsetto di ingresso e la rotaia comune al morsetto COM. Gli assili che cortocircuitano entrambe le rotaie completano il circuito verso la massa e attivano l'ingresso.

⚠️ *Quando si utilizza la versione GND su un plastico a 3 rotaie, è indispensabile che la centrale e i booster siano del tipo a massa comune. Se si utilizza la versione GND con una centrale a ponte H, si danneggerà la centrale. Utilizzare invece la variante OPTO.*

---

**OS-S88n OPTO — optoisolato**

Cablaggio della versione OPTO

Collegare l'uscita del segnale del sensore al morsetto di ingresso e la massa del sensore al morsetto COM. La tensione di ingresso dipende dall'alimentazione del sensore; verificare le indicazioni sulla scheda per il campo supportato.

---

**Collegamento a cascata di più moduli**

Collegamento a cascata di più moduli OS-S88n

Collegare l'OUT di ciascun modulo all'IN del successivo. L'OUT del primo modulo va alla centrale. Lasciare vuoto il connettore IN dell'ultimo modulo della catena.

---

## Risoluzione dei Problemi

**Nessun feedback ricevuto**
- Verificare il cablaggio RJ-45 e confermare la presenza di tutti gli 8 conduttori
- Confermare che il connettore OUT sia orientato verso la centrale (non IN)
- Verificare che l'intervallo di indirizzi del modulo nel software corrisponda alla posizione del modulo nella catena

**Attivazioni false**
- Versione GND: verificare la presenza di cortocircuiti nel cablaggio o interferenze tra le sezioni di rilevamento
- Versione CS: verificare il consumo di corrente minimo — i vagoni con soli LED potrebbero necessitare di un resistore per attivare il rilevamento
- Versione OPTO: verificare la tensione di alimentazione del sensore e la polarità del segnale
- Evitare cavi Ethernet più lunghi di 5 m

**Feedback in ritardo**
- Ridurre l'intervallo di polling nella centrale o nel software su PC
- Verificare il corretto indirizzamento degli ingressi nel software

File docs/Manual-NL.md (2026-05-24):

> 🌐 &nbsp; [🇬🇧 EN](Manual-EN.md) &nbsp;|&nbsp; [🇩🇪 DE](Manual-DE.md) &nbsp;|&nbsp; [🇫🇷 FR](Manual-FR.md) &nbsp;|&nbsp; 🇳🇱 NL &nbsp;|&nbsp; [🇪🇸 ES](Manual-ES.md) &nbsp;|&nbsp; [🇮🇹 IT](Manual-IT.md) &nbsp;|&nbsp; [🇵🇱 PL](Manual-PL.md) &nbsp;|&nbsp; [🇨🇿 CS](Manual-CS.md) &nbsp;|&nbsp; [🇩🇰 DA](Manual-DA.md) &nbsp;|&nbsp; [🇳🇴 NO](Manual-NO.md) &nbsp;|&nbsp; [🇸🇪 SV](Manual-SV.md) &nbsp;|&nbsp; [🇭🇺 HU](Manual-HU.md) &nbsp;|&nbsp; [🇵🇹 PT](Manual-PT.md)

# OS-S88n Terugmeld­modules Handleiding

**Ondersteunt: OS-S88n GND · OS-S88n CS · OS-S88n OPTO**

Alle drie OS-S88n module­varianten

*Van links naar rechts: OS-S88n CS, OS-S88n GND, OS-S88n OPTO*

---

## Inleiding

De OS-S88n-modules bieden terugmeld­functionaliteit voor DCC-modelbanen via het gestandaardiseerde S88n-protocol. Met deze modules kunt u blokvrijmelding en baan­gebeurtenissen in real time bewaken, waarbij gegevens naar uw centrale of pc-gestuurd bestuurdings­programma worden gestuurd.

Er zijn drie varianten beschikbaar voor verschillende detectie­behoeften:

- **OS-S88n GND** — massa­contact­detectie, geschikt voor 3-rail (Märklin-stijl) banen
- **OS-S88n CS** — stroom­detectie, geschikt voor 2-rail en 3-rail digitale banen
- **OS-S88n OPTO** — optisch geïsoleerde digitale ingangen, voor gebruik met externe sensoren zoals IR-detectoren of Hall-sensoren

Alle varianten omvatten:

- Doorlus­schakelbare S88n-aansluitingen (RJ-45)
- Schroef­klemmen voor alle sensor­aansluitingen
- Compatibiliteit met alle grote centrales en software (iTrain, Rocrail, Windigipet, enz.)

---

## Module­varianten

### OS-S88n GND — Massa­contact­detectie

OS-S88n GND module

De GND-module heeft 16 ingangen die worden geactiveerd wanneer de ingang naar massa wordt getrokken. Compatibele sensoren en detectie­methoden zijn onder andere:

- Rietcontacten
- Drukknopen
- Metalen wielstellen die de rails overbruggen op een 3-rail (Märklin-stijl) baan

⚠️ **Belangrijk — 3-rail banen:** Bij gebruik van de GND-module op een 3-rail baan **moeten** uw centrale en alle versterkers van het gemeenschappelijk massa-type zijn. Als uw centrale een H-brug­uitgang gebruikt, zal het gebruik van de GND-module **uw centrale beschadigen**. Gebruik in dat geval de OPTO-variant.

---

### OS-S88n CS — Stroom­detectie

OS-S88n CS module

De CS-module heeft 16 ingangen die worden geactiveerd wanneer er stroom door een bewaakt baan­gedeelte wordt getrokken. Al het rollend materieel dat stroom afneemt, activeert de detectie, waaronder:

- Locomotieven
- Verlichte rijtuigen
- Wagons voorzien van een weerstand voor detectie­doeleinden

Geschikt voor zowel 2-rail als 3-rail digitale banen.

---

### OS-S88n OPTO — Optisch geïsoleerde ingangs­detectie

OS-S88n OPTO module

De OPTO-module heeft 16 volledig optisch geïsoleerde digitale ingangen. Volledige galvanische isolatie tussen de sensoren en de S88-bus maakt deze variant ideaal voor:

- IR-detectoren
- Hall-sensoren
- Schakelaars op grote afstand van de module
- Gevoelige omgevingen
- Banen waarbij aardlussen of elektrische interferentie een probleem zijn

⚠️ De OPTO-module detecteert **niet** op zichzelf baanvrijmelding — er zijn externe sensoren nodig die een logisch signaal leveren.

---

## Kenmerken

- Volledig compatibel met het S88n-terugmeld­protocol
- RJ-45-aansluitingen voor het in serie schakelen van modules
- 16 ingangen per module
- Tot 31 modules in één keten aansluiten
- Schroef­klemmen voor alle sensor­aansluitingen
- OPTO-versie biedt volledige galvanische isolatie

---

## Modules aansluiten

### Voeding en signaal

Sluit de modules aan op uw centrale via standaard UTP Ethernet-kabels. **Alle 8 draden moeten zijn aangesloten** — vermijd goedkoop gemaakte patchkabels die interne draden weglaten.

- **S88n OUT**-aansluiting → S88n-ingang van de centrale (of de IN van de vorige module)
- **S88n IN**-aansluiting → volgende module in de keten (laat leeg op de laatste module)

### Sensor­bedrading

**OS-S88n CS — stroom­detectie**

Bedrading van de stroom­detectie versie

Leid de baan­voedings­draden voor elke detectie­sectie door de stroom­sensor­ingangen. Een trein die stroom afneemt in die sectie activeert de overeenkomstige ingang.

---

**OS-S88n GND — massa­contact**

Bedrading van de GND-versie

Sluit één rail (of sensor­uitgang) aan op een ingangs­klem en de gemeenschappelijke rail op de COM-klem. Wielstellen die beide rails overbruggen sluiten het circuit naar massa en activeren de ingang.

⚠️ *Bij gebruik van de GND-versie op een 3-rail baan is het absoluut noodzakelijk dat de centrale en versterkers van het gemeenschappelijk massa-type zijn. Als u de GND-versie gebruikt met een H-brug­centrale, vernietigt u uw centrale. Gebruik in dat geval de OPTO-variant.*

---

**OS-S88n OPTO — optisch geïsoleerd**

Bedrading van de OPTO-versie

Sluit de signaal­uitgang van uw sensor aan op de ingangs­klem en de sensor­massa op de COM-klem. De ingangsspanning hangt af van de voeding van uw sensor; controleer de PCB-markeringen voor het ondersteunde bereik.

---

**Meerdere modules in serie schakelen**

Meerdere OS-S88n-modules in serie schakelen

Verbind de OUT van elke module met de IN van de volgende. De OUT van de eerste module gaat naar de centrale. Laat de IN-aansluiting van de laatste module in de keten leeg.

---

## Probleemoplossing

**Geen terugmelding ontvangen**
- Controleer de RJ-45-bedrading en bevestig dat alle 8 geleiders aanwezig zijn
- Bevestig dat de OUT-aansluiting naar de centrale wijst (niet IN)
- Controleer of het adresbereik van de module in uw software overeenkomt met de positie van de module in de keten

**Valse activering**
- GND-versie: controleer op bedradingskort­sluitingen of interferentie tussen detectie­secties
- CS-versie: controleer minimale stroom­afname — wagons met alleen LED-verlichting hebben mogelijk een weerstand nodig om detectie te activeren
- OPTO-versie: controleer sensor­voedings­spanning en signaal­polariteit
- Vermijd Ethernet-kabels langer dan 5 m

**Vertraagde terugmelding**
- Verlaag het poll-interval in uw centrale of pc-software
- Controleer de juiste ingangs­adressering in uw software

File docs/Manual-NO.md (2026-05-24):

> 🌐 &nbsp; [🇬🇧 EN](Manual-EN.md) &nbsp;|&nbsp; [🇩🇪 DE](Manual-DE.md) &nbsp;|&nbsp; [🇫🇷 FR](Manual-FR.md) &nbsp;|&nbsp; [🇳🇱 NL](Manual-NL.md) &nbsp;|&nbsp; [🇪🇸 ES](Manual-ES.md) &nbsp;|&nbsp; [🇮🇹 IT](Manual-IT.md) &nbsp;|&nbsp; [🇵🇱 PL](Manual-PL.md) &nbsp;|&nbsp; [🇨🇿 CS](Manual-CS.md) &nbsp;|&nbsp; [🇩🇰 DA](Manual-DA.md) &nbsp;|&nbsp; 🇳🇴 NO &nbsp;|&nbsp; [🇸🇪 SV](Manual-SV.md) &nbsp;|&nbsp; [🇭🇺 HU](Manual-HU.md) &nbsp;|&nbsp; [🇵🇹 PT](Manual-PT.md)

# OS-S88n Tilbakemeldingsmoduler Manual

**Støtter: OS-S88n GND · OS-S88n CS · OS-S88n OPTO**

Alle tre OS-S88n-modulvarianter

*Fra venstre til høyre: OS-S88n CS, OS-S88n GND, OS-S88n OPTO*

---

## Innledning

OS-S88n-modulene gir tilbakemeldings-funksjonalitet for DCC-modelljernbaner ved hjelp av den standardiserte S88n-protokollen. Disse modulene muliggjør sanntidsovervåking av blokkbelegg og anleggshendelser, og sender data til sentralstasjonen din eller PC-basert styringsprogramvare.

Tre varianter er tilgjengelige for å dekke ulike deteksjonsbehov:

- **OS-S88n GND** — jordkontakt-deteksjon, egnet for 3-skinne-anlegg (Märklin-stil)
- **OS-S88n CS** — strømsansedeteksjon, egnet for 2-skinne- og 3-skinne-digitale anlegg
- **OS-S88n OPTO** — optoisolerte digitale innganger, for bruk med eksterne sensorer som IR-detektorer eller Hall-sensorer

Alle varianter inkluderer:

- Lenke-kjede S88n-koblinger (RJ-45)
- Skrueterminaler for alle sensortilkoblinger
- Kompatibilitet med alle større sentralstasjoner og programvare (iTrain, Rocrail, Windigipet, osv.)

---

## Modulvarianter

### OS-S88n GND — Jordkontakt-deteksjon

OS-S88n GND-kort

GND-modulen har 16 innganger som utløses når inngangen trekkes til jord. Kompatible sensorer og deteksjonsmetoder inkluderer:

- Rørbrytere
- Trykknapper
- Metallhjulsett som broer skinnene på et 3-skinne-anlegg (Märklin-stil)

⚠️ **Viktig — 3-skinne-anlegg:** Når du bruker GND-modulen på et 3-skinne-anlegg, **må** sentralstasjonen din og alle forsterkere være av fellesjord-type. Hvis sentralstasjonen din bruker H-bro-utgang, vil bruk av GND-modulen **ødelegge sentralstasjonen**. Bruk OPTO-varianten i stedet i så fall.

---

### OS-S88n CS — Strømsansing

OS-S88n CS-kort

CS-modulen har 16 innganger som aktiveres hver gang strøm trekkes gjennom et overvåket sporparti. Alt rullende materiell som trekker strøm vil utløse deteksjon, inkludert:

- Lokomotiver
- Belyste vogner
- Godsvogner utstyrt med motstand for deteksjonsformål

Egnet for både 2-skinne- og 3-skinne-digitale anlegg.

---

### OS-S88n OPTO — Optoisolert inngångsdeteksjon

OS-S88n OPTO-kort

OPTO-modulen har 16 fullt optoisolerte digitale innganger. Full galvanisk isolasjon mellom sensorene og S88-bussen gjør denne varianten ideell for:

- IR-detektorer
- Hall-sensorer
- Brytere plassert langt fra modulen
- Støyfølsomme miljøer
- Anlegg der jordslynger eller elektrisk interferens er et problem

⚠️ OPTO-modulen registrerer **ikke** sporsbelegg på egenhånd — den krever eksterne sensorer som gir et logikknivå-signal.

---

## Egenskaper

- Fullt kompatibel med S88n tilbakemeldingsprotokollen
- RJ-45-koblinger for kjeding av moduler
- 16 innganger per modul
- Stabble opptil 31 moduler i en enkelt kjede
- Skrueterminaler for alle sensortilkoblinger
- OPTO-versjonen gir full galvanisk isolasjon

---

## Tilkobling av modulene

### Strøm og signal

Koble modulene til sentralstasjonen din med standard UTP Ethernet-kabler. **Alle 8 ledere må være tilkoblet** — unngå billig produserte patch-kabler som mangler interne ledere.

- **S88n OUT**-kobling → sentralstasjonens S88n-inngang (eller forrige moduls IN)
- **S88n IN**-kobling → neste modul i kjeden (la stå tom på den siste modulen)

### Sensor-kabling

**OS-S88n CS — strømsansing**

Kabling av strømsanseversjon

Led spormatingsledn. for hvert deteksjonsparti gjennom strømsansingangene. Ethvert tog som trekker strøm i det partiet aktiverer tilsvarende inngang.

---

**OS-S88n GND — jordkontakt**

Kabling av GND-versjonen

Koble én skinne (eller sensorutgang) til en inngangsterminal og den felles skinnen til COM-terminalen. Hjulsett som broer begge skinner fullfører kretsen til jord og utløser inngangen.

⚠️ *Ved bruk av GND-versjonen på et 3-skinne-anlegg er det avgjørende at sentralstasjonen og forsterkerne er av fellesjord-type. Hvis du bruker GND-versjonen med en H-bro-sentralstasjon, vil du ødelegge sentralstasjonen. Bruk OPTO-varianten i stedet.*

---

**OS-S88n OPTO — optoisolert**

Kabling av OPTO-versjonen

Koble sensorens signalutgang til inngangsterminalen og sensorgrunnen til COM-terminalen. Inngangsspenningen avhenger av sensorens forsyning; sjekk kortets merkinger for støttet område.

---

**Kjeding av flere moduler**

Kjeding av flere OS-S88n-moduler

Koble OUT fra hver modul til IN på den neste. Den første modulens OUT går til sentralstasjonen. La IN-koblingen på den siste modulen i kjeden stå tom.

---

## Feilsøking

**Ingen tilbakemelding mottatt**
- Sjekk RJ-45-kabling og bekreft at alle 8 ledere er til stede
- Bekreft at OUT-koblingen peker mot sentralstasjonen (ikke IN)
- Verifiser at moduladresseområdet i programvaren din samsvarer med modulens posisjon i kjeden

**Falske utløsere**
- GND-versjon: sjekk for kabelkortslutninger eller interferens mellom deteksjonspartier
- CS-versjon: sjekk minimalt strømtrekk — vogner med kun LED-er kan trenge en motstand for å utløse deteksjon
- OPTO-versjon: sjekk sensorforsyningsspenning og signalpolaritet
- Unngå Ethernet-kabler lengre enn 5 m

**Forsinket tilbakemelding**
- Reduser pollingsintervallet i sentralstasjonen eller PC-programvaren din
- Verifiser korrekt inngangadressering i programvaren din

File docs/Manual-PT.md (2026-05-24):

> 🌐 &nbsp; [🇬🇧 EN](Manual-EN.md) &nbsp;|&nbsp; [🇩🇪 DE](Manual-DE.md) &nbsp;|&nbsp; [🇫🇷 FR](Manual-FR.md) &nbsp;|&nbsp; [🇳🇱 NL](Manual-NL.md) &nbsp;|&nbsp; [🇪🇸 ES](Manual-ES.md) &nbsp;|&nbsp; [🇮🇹 IT](Manual-IT.md) &nbsp;|&nbsp; [🇵🇱 PL](Manual-PL.md) &nbsp;|&nbsp; [🇨🇿 CS](Manual-CS.md) &nbsp;|&nbsp; [🇩🇰 DA](Manual-DA.md) &nbsp;|&nbsp; [🇳🇴 NO](Manual-NO.md) &nbsp;|&nbsp; [🇸🇪 SV](Manual-SV.md) &nbsp;|&nbsp; [🇭🇺 HU](Manual-HU.md) &nbsp;|&nbsp; 🇵🇹 PT

# Manual dos Módulos de Retorno OS-S88n

**Suporta: OS-S88n GND · OS-S88n CS · OS-S88n OPTO**

As três variantes do módulo OS-S88n

*Da esquerda para a direita: OS-S88n CS, OS-S88n GND, OS-S88n OPTO*

---

## Introdução

Os módulos OS-S88n fornecem funcionalidade de retorno para ferrovias em miniatura DCC utilizando o protocolo S88n normalizado. Estes módulos permitem a monitorização em tempo real da ocupação de blocos e eventos da maquete, enviando dados para a sua central de comando ou software de controlo em PC.

Estão disponíveis três variantes para satisfazer diferentes necessidades de detecção:

- **OS-S88n GND** — detecção por contacto com a massa, adequada para maquetes de 3 carris (tipo Märklin)
- **OS-S88n CS** — detecção por detecção de corrente, adequada para maquetes digitais de 2 e 3 carris
- **OS-S88n OPTO** — entradas digitais com isolamento óptico, para uso com sensores externos como detectores IR ou sensores Hall

Todas as variantes incluem:

- Conectores S88n encadeáveis (RJ-45)
- Bornes de parafuso para todas as ligações de sensores
- Compatibilidade com todas as principais centrais de comando e software (iTrain, Rocrail, Windigipet, etc.)

---

## Variantes dos Módulos

### OS-S88n GND — Detecção por Contacto com Massa

Placa OS-S88n GND

O módulo GND tem 16 entradas que disparam quando a entrada é ligada à massa. Os sensores e métodos de detecção compatíveis incluem:

- Contactos de reed
- Botões de pressão
- Rodados metálicos que fazem ponte entre os carris numa maquete de 3 carris (tipo Märklin)

⚠️ **Importante — maquetes de 3 carris:** Ao utilizar o módulo GND numa maquete de 3 carris, a sua central de comando e todos os boosters **devem** ser do tipo com massa comum. Se a sua central utiliza uma saída em ponte H, o uso do módulo GND **danificará a central**. Utilize a variante OPTO nesse caso.

---

### OS-S88n CS — Detecção de Corrente

Placa OS-S88n CS

O módulo CS tem 16 entradas que se activam sempre que é consumida corrente numa secção de via monitorizada. Qualquer material circulante que consuma corrente dispara a detecção, incluindo:

- Locomotivas
- Carruagens iluminadas
- Vagões equipados com resistência para fins de detecção

Adequado para maquetes digitais de 2 e 3 carris.

---

### OS-S88n OPTO — Detecção de Entrada com Isolamento Óptico

Placa OS-S88n OPTO

O módulo OPTO tem 16 entradas digitais com isolamento óptico total. O isolamento galvânico completo entre os sensores e o barramento S88 torna esta variante ideal para:

- Detectores IR
- Sensores Hall
- Interruptores localizados a grande distância do módulo
- Ambientes sujeitos a ruído eléctrico
- Maquetes onde os anéis de terra ou as interferências eléctricas são uma preocupação

⚠️ O módulo OPTO **não** detecta ocupação de via por si próprio — requer sensores externos que forneçam um sinal de nível lógico.

---

## Características

- Totalmente compatível com o protocolo de retorno S88n
- Conectores RJ-45 para encadeamento de módulos
- 16 entradas por módulo
- Ligação de até 31 módulos numa única cadeia
- Bornes de parafuso para todas as ligações de sensores
- A versão OPTO oferece isolamento galvânico total

---

## Ligação dos Módulos

### Alimentação e Sinal

Ligue os módulos à sua central de comando utilizando cabos Ethernet UTP normais. **Todos os 8 fios devem estar ligados** — evite cabos de ligação de baixa qualidade que omitem fios internos.

- Conector **S88n OUT** → entrada S88n da central de comando (ou o IN do módulo anterior)
- Conector **S88n IN** → módulo seguinte na cadeia (deixe vazio no último módulo)

### Ligação dos Sensores

**OS-S88n CS — detecção de corrente**

Ligação da versão de Detecção de Corrente

Encaminhe os fios de alimentação de via de cada secção de detecção pelas entradas de detecção de corrente. Qualquer comboio que consuma corrente nessa secção activa a entrada correspondente.

---

**OS-S88n GND — contacto com massa**

Ligação da versão GND

Ligue um carril (ou saída do sensor) a um terminal de entrada e o carril comum ao terminal COM. Os rodados a fazer ponte entre ambos os carris completam o circuito para a massa e disparam a entrada.

⚠️ *Ao utilizar a versão GND numa maquete de 3 carris, é imperativo que a central de comando e os boosters sejam do tipo com massa comum. Se utilizar a versão GND com uma central com saída em ponte H, destruirá a central. Utilize a variante OPTO em alternativa.*

---

**OS-S88n OPTO — isolamento óptico**

Ligação da versão OPTO

Ligue a saída de sinal do sensor ao terminal de entrada e a massa do sensor ao terminal COM. A tensão de entrada depende da alimentação do sensor; consulte as marcações da placa para o intervalo suportado.

---

**Encadeamento de múltiplos módulos**

Encadeamento de vários módulos OS-S88n

Ligue o OUT de cada módulo ao IN do seguinte. O OUT do primeiro módulo vai para a central de comando. Deixe o conector IN do último módulo na cadeia vazio.

---

## Resolução de Problemas

**Nenhum retorno recebido**
- Verifique a cablagem RJ-45 e confirme que todos os 8 condutores estão presentes
- Confirme que o conector OUT aponta para a central de comando (e não o IN)
- Verifique se o intervalo de endereços do módulo no seu software corresponde à posição do módulo na cadeia

**Disparos falsos**
- Versão GND: verifique curto-circuitos na cablagem ou interferências entre secções de detecção
- Versão CS: verifique o consumo mínimo de corrente — vagões apenas com LED podem necessitar de uma resistência para disparar a detecção
- Versão OPTO: verifique a tensão de alimentação do sensor e a polaridade do sinal
- Evite cabos Ethernet com mais de 5 m

**Retorno com atraso**
- Reduza o intervalo de interrogação na sua central de comando ou software de PC
- Verifique o endereçamento correcto das entradas no seu software

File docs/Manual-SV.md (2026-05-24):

> 🌐 &nbsp; [🇬🇧 EN](Manual-EN.md) &nbsp;|&nbsp; [🇩🇪 DE](Manual-DE.md) &nbsp;|&nbsp; [🇫🇷 FR](Manual-FR.md) &nbsp;|&nbsp; [🇳🇱 NL](Manual-NL.md) &nbsp;|&nbsp; [🇪🇸 ES](Manual-ES.md) &nbsp;|&nbsp; [🇮🇹 IT](Manual-IT.md) &nbsp;|&nbsp; [🇵🇱 PL](Manual-PL.md) &nbsp;|&nbsp; [🇨🇿 CS](Manual-CS.md) &nbsp;|&nbsp; [🇩🇰 DA](Manual-DA.md) &nbsp;|&nbsp; [🇳🇴 NO](Manual-NO.md) &nbsp;|&nbsp; 🇸🇪 SV &nbsp;|&nbsp; [🇭🇺 HU](Manual-HU.md) &nbsp;|&nbsp; [🇵🇹 PT](Manual-PT.md)

# OS-S88n Återkopplingsmoduler Manual

**Stöder: OS-S88n GND · OS-S88n CS · OS-S88n OPTO**

Alla tre OS-S88n-modulvarianterna

*Från vänster till höger: OS-S88n CS, OS-S88n GND, OS-S88n OPTO*

---

## Introduktion

OS-S88n-modulerna tillhandahåller återkopplingsfunktionalitet för DCC-modelljärnvägar med det standardiserade S88n-protokollet. Dessa moduler möjliggör realtidsövervakning av blockövervakning och banor, och skickar data till din kommandostation eller PC-baserade styrsoftware.

Tre varianter finns tillgängliga för att passa olika detektionsbehov:

- **OS-S88n GND** — jordkontaktdetektering, lämplig för 3-skena-banor (Märklin-stil)
- **OS-S88n CS** — strömavkänningsdetektering, lämplig för 2-skena- och 3-skena-digitala banor
- **OS-S88n OPTO** — optoelektriskt isolerade digitala ingångar, för användning med externa sensorer såsom IR-detektorer eller Hall-sensorer

Alla varianter inkluderar:

- Sammankopplingsbara S88n-kontakter (RJ-45)
- Skruvplintrar för alla sensoranslutningar
- Kompatibilitet med alla större kommandostationer och program (iTrain, Rocrail, Windigipet m.fl.)

---

## Modulvarianter

### OS-S88n GND — Jordkontaktdetektering

OS-S88n GND-kort

GND-modulen har 16 ingångar som utlöses när ingången dras till jord. Kompatibla sensorer och detektionsmetoder inkluderar:

- Reedbrytare
- Tryckknappar
- Metallhjulsatser som bryggar räls i ett 3-skena-system (Märklin-stil)

⚠️ **Viktigt — 3-skena-banor:** När du använder GND-modulen på en 3-skena-bana **måste** din kommandostation och alla boostrar vara av gemensam jord-typ. Om din kommandostation använder en H-bryggeutgång kommer användningen av GND-modulen **att skada din kommandostation**. Använd OPTO-varianten i det fallet.

---

### OS-S88n CS — Strömavkänning

OS-S88n CS-kort

CS-modulen har 16 ingångar som aktiveras när ström dras genom ett övervakat spåravsnitt. All rullande materiel som drar ström utlöser detektering, inklusive:

- Lok
- Belysta vagnar
- Vagnar utrustade med ett motstånd för detektionsändamål

Lämplig för både 2-skena- och 3-skena-digitala banor.

---

### OS-S88n OPTO — Optoelektriskt isolerad ingångsdetektering

OS-S88n OPTO-kort

OPTO-modulen har 16 fullständigt optoelektriskt isolerade digitala ingångar. Fullständig galvanisk isolering mellan sensorerna och S88-bussen gör denna variant idealisk för:

- IR-detektorer
- Hall-sensorer
- Brytare placerade långt från modulen
- Brusskänsliga miljöer
- Banor där jordloopar eller elektrisk störning är ett problem

⚠️ OPTO-modulen detekterar **inte** spårbeläggning av sig självt — den kräver externa sensorer som ger en logikspänningssignal.

---

## Funktioner

- Fullt kompatibel med S88n återkopplingsprotokoll
- RJ-45-kontakter för seriekoppling av moduler
- 16 ingångar per modul
- Koppla upp till 31 moduler i en enda kedja
- Skruvplintrar för alla sensoranslutningar
- OPTO-versionen ger fullständig galvanisk isolering

---

## Anslutning av modulerna

### Ström och signal

Anslut modulerna till din kommandostation med standard UTP Ethernet-kablar. **Alla 8 ledare måste vara anslutna** — undvik billigt tillverkade patchkablar som utelämnar interna ledare.

- **S88n OUT**-kontakt → kommandostationens S88n-ingång (eller föregående moduls IN)
- **S88n IN**-kontakt → nästa modul i kedjan (lämna tom på den sista modulen)

### Sensorkoppling

**OS-S88n CS — strömavkänning**

Koppling av strömavkänningsversionen

Led spårmatningskablarna för varje detektionssektion genom strömavkänningsingångarna. Varje tåg som drar ström i det avsnittet aktiverar motsvarande ingång.

---

**OS-S88n GND — jordkontakt**

Koppling av GND-versionen

Anslut en räls (eller sensorutgång) till en ingångsplintt och den gemensamma räls till COM-plintten. Hjulset som bryggar båda rälsen slutför kretsen till jord och utlöser ingången.

⚠️ *När du använder GND-versionen på en 3-skena-bana är det absolut nödvändigt att kommandostationen och boostrar är av gemensam jord-typ. Om du använder GND-versionen med en H-bryggkommandostation förstör du din kommandostation. Använd OPTO-varianten istället.*

---

**OS-S88n OPTO — optoelektriskt isolerad**

Koppling av OPTO-versionen

Anslut sensorns signalutgång till ingångsplintten och sensorns jord till COM-plintten. Ingångsspänningen beror på din sensors matning; kontrollera kortets markeringar för det stödda området.

---

**Seriekoppling av flera moduler**

Seriekoppling av flera OS-S88n-moduler

Anslut OUT på varje modul till IN på nästa. Den första modulens OUT går till kommandostationen. Lämna IN-kontakten på den sista modulen i kedjan tom.

---

## Felsökning

**Ingen återkoppling mottagen**
- Kontrollera RJ-45-kablarna och bekräfta att alla 8 ledare är närvarande
- Bekräfta att OUT-kontakten pekar mot kommandostationen (inte IN)
- Verifiera att modulens adressintervall i din programvara stämmer med modulens position i kedjan

**Falska utlösningar**
- GND-version: kontrollera för kabelshortar eller störningar mellan detektionsavsnitt
- CS-version: kontrollera minsta strömförbrukning — LED-enbart vagnar kan behöva ett motstånd för att utlösa detektering
- OPTO-version: kontrollera sensorns matningsspänning och signalpolaritet
- Undvik Ethernet-kablar längre än 5 m

**Fördröjd återkoppling**
- Minska pollingintervallet i din kommandostation eller PC-programvara
- Verifiera korrekt ingångsadressering i din programvara

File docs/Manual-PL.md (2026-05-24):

> 🌐 &nbsp; [🇬🇧 EN](Manual-EN.md) &nbsp;|&nbsp; [🇩🇪 DE](Manual-DE.md) &nbsp;|&nbsp; [🇫🇷 FR](Manual-FR.md) &nbsp;|&nbsp; [🇳🇱 NL](Manual-NL.md) &nbsp;|&nbsp; [🇪🇸 ES](Manual-ES.md) &nbsp;|&nbsp; [🇮🇹 IT](Manual-IT.md) &nbsp;|&nbsp; 🇵🇱 PL &nbsp;|&nbsp; [🇨🇿 CS](Manual-CS.md) &nbsp;|&nbsp; [🇩🇰 DA](Manual-DA.md) &nbsp;|&nbsp; [🇳🇴 NO](Manual-NO.md) &nbsp;|&nbsp; [🇸🇪 SV](Manual-SV.md) &nbsp;|&nbsp; [🇭🇺 HU](Manual-HU.md) &nbsp;|&nbsp; [🇵🇹 PT](Manual-PT.md)

# Instrukcja modułów zwrotnych OS-S88n

**Obsługuje: OS-S88n GND · OS-S88n CS · OS-S88n OPTO**

Wszystkie trzy warianty modułów OS-S88n

*Od lewej do prawej: OS-S88n CS, OS-S88n GND, OS-S88n OPTO*

---

## Wprowadzenie

Moduły OS-S88n zapewniają funkcję zwrotną dla makiet kolejowych DCC przy użyciu standardowego protokołu S88n. Moduły te umożliwiają monitorowanie w czasie rzeczywistym zajętości blokady i zdarzeń na makiecie, wysyłając dane do stacji sterującej lub oprogramowania sterującego na PC.

Dostępne są trzy warianty dostosowane do różnych potrzeb detekcji:

- **OS-S88n GND** — detekcja kontaktu z masą, odpowiednia dla makiet 3-szynowych (w stylu Märklin)
- **OS-S88n CS** — detekcja prądu, odpowiednia dla cyfrowych makiet 2-szynowych i 3-szynowych
- **OS-S88n OPTO** — optoizolowane wejścia cyfrowe, do użytku z zewnętrznymi czujnikami, takimi jak czujniki IR lub czujniki Halla

Wszystkie warianty zawierają:

- Łańcuchowalne złącza S88n (RJ-45)
- Zaciski śrubowe do wszystkich połączeń czujników
- Kompatybilność ze wszystkimi głównymi stacjami sterującymi i oprogramowaniem (iTrain, Rocrail, Windigipet itp.)

---

## Warianty modułów

### OS-S88n GND — detekcja kontaktu z masą

Płytka OS-S88n GND

Moduł GND ma 16 wejść, które wyzwalają się, gdy wejście zostanie podciągnięte do masy. Kompatybilne czujniki i metody detekcji obejmują:

- Kontraktrony (przełączniki trzcinowe)
- Przyciski
- Metalowe zestawy kół zwierające szyny na makiecie 3-szynowej (w stylu Märklin)

⚠️ **Ważne — makiety 3-szynowe:** Przy używaniu modułu GND na makiecie 3-szynowej stacja sterująca i wszystkie wzmacniacze **muszą** być typu z wspólną masą. Jeśli stacja sterująca ma wyjście z mostkiem H, używanie modułu GND **uszkodzi stację sterującą**. Zamiast tego użyj wariantu OPTO.

---

### OS-S88n CS — detekcja prądu

Płytka OS-S88n CS

Moduł CS ma 16 wejść, które aktywują się za każdym razem, gdy przez monitorowany odcinek torowy przepływa prąd. Każdy tabor pobierający prąd wyzwoli detekcję, w tym:

- Lokomotywy
- Wagony z oświetleniem
- Wagony wyposażone w rezystor do celów detekcji

Odpowiedni zarówno dla cyfrowych makiet 2-szynowych, jak i 3-szynowych.

---

### OS-S88n OPTO — optoizolowana detekcja wejść

Płytka OS-S88n OPTO

Moduł OPTO ma 16 w pełni optoizolowanych wejść cyfrowych. Pełna izolacja galwaniczna między czujnikami a magistralą S88 sprawia, że ten wariant jest idealny dla:

- Czujników IR
- Czujników Halla
- Przełączników zlokalizowanych daleko od modułu
- Środowisk wrażliwych na zakłócenia
- Makiet, w których problematyczne są pętle masy lub zakłócenia elektryczne

⚠️ Moduł OPTO **nie wykrywa** sam z siebie zajętości toru — wymaga zewnętrznych czujników dostarczających sygnał na poziomie logicznym.

---

## Właściwości

- W pełni kompatybilny z protokołem zwrotnym S88n
- Złącza RJ-45 do łańcuchowego łączenia modułów
- 16 wejść na moduł
- Łączenie w łańcuchy do 31 modułów
- Zaciski śrubowe do wszystkich połączeń czujników
- Wersja OPTO zapewnia pełną izolację galwaniczną

---

## Podłączanie modułów

### Zasilanie i sygnał

Podłącz moduły do stacji sterującej przy użyciu standardowych kabli Ethernet UTP. **Wszystkie 8 przewodów musi być podłączonych** — unikaj tanich kabli krosowniczych, którym brakuje wewnętrznych przewodów.

- Złącze **S88n OUT** → wejście S88n stacji sterującej (lub wejście IN poprzedniego modułu)
- Złącze **S88n IN** → następny moduł w łańcuchu (pozostaw puste na ostatnim module)

### Okablowanie czujników

**OS-S88n CS — detekcja prądu**

Okablowanie wersji z detekcją prądu

Przeprowadź przewody zasilania torowego dla każdej sekcji detekcji przez wejścia czujnika prądu. Każdy pociąg pobierający prąd w tej sekcji aktywuje odpowiednie wejście.

---

**OS-S88n GND — kontakt z masą**

Okablowanie wersji GND

Podłącz jedną szynę (lub wyjście czujnika) do zacisku wejściowego, a wspólną szynę do zacisku COM. Zestawy kół zwierające obie szyny domykają obwód do masy i wyzwalają wejście.

⚠️ *Przy używaniu wersji GND na makiecie 3-szynowej bezwzględnie konieczne jest, aby stacja sterująca i wzmacniacze były typu z wspólną masą. Używanie wersji GND ze stacją sterującą z mostkiem H spowoduje jej uszkodzenie. Zamiast tego użyj wariantu OPTO.*

---

**OS-S88n OPTO — optoizolowany**

Okablowanie wersji OPTO

Podłącz wyjście sygnałowe czujnika do zacisku wejściowego, a masę czujnika do zacisku COM. Napięcie wejściowe zależy od zasilania czujnika; sprawdź oznaczenia na płytce pod kątem obsługiwanego zakresu.

---

**Łańcuchowe łączenie wielu modułów**

Łańcuchowe łączenie kilku modułów OS-S88n

Podłącz OUT każdego modułu do IN następnego. OUT pierwszego modułu trafia do stacji sterującej. Złącze IN ostatniego modułu w łańcuchu pozostaw puste.

---

## Rozwiązywanie problemów

**Brak sygnału zwrotnego**
- Sprawdź okablowanie RJ-45 i upewnij się, że wszystkie 8 przewodów jest podłączonych
- Upewnij się, że złącze OUT kieruje się w stronę stacji sterującej (nie IN)
- Sprawdź w oprogramowaniu, czy zakres adresów modułu odpowiada pozycji modułu w łańcuchu

**Fałszywe wyzwolenia**
- Wersja GND: sprawdź zwarcia w okablowaniu lub zakłócenia między sekcjami detekcji
- Wersja CS: sprawdź minimalny pobór prądu — wagony wyłącznie z LED mogą wymagać rezystora do wyzwolenia detekcji
- Wersja OPTO: sprawdź napięcie zasilania czujnika i polaryzację sygnału
- Unikaj kabli Ethernet dłuższych niż 5 m

**Opóźniony sygnał zwrotny**
- Skróć interwał odpytywania w stacji sterującej lub oprogramowaniu na PC
- Sprawdź prawidłowe adresowanie wejść w oprogramowaniu

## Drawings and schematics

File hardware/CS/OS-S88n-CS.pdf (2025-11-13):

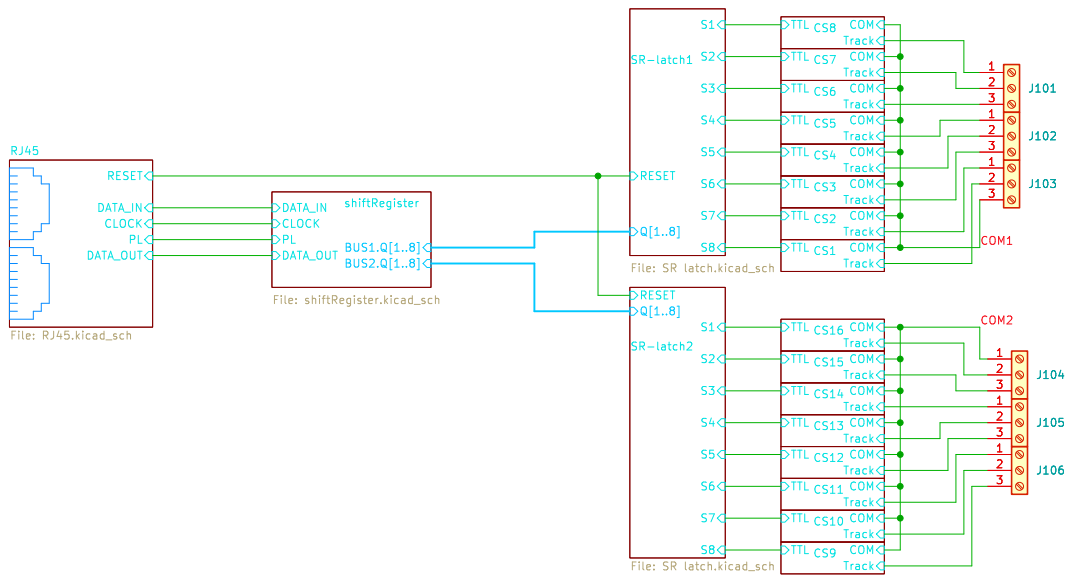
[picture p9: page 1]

Id: 1/21 Title: File: OS-S88n-CS.kicad_sch Sheet: /

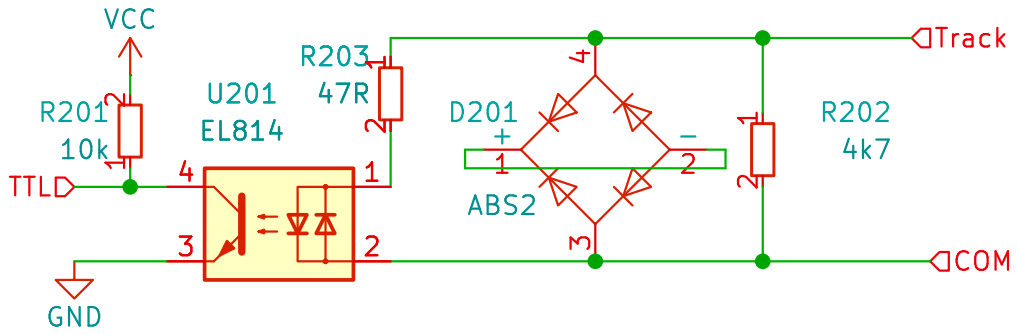
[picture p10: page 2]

Id: 2/21 Title: File: current sensor.kicad_sch Sheet: /CS1/

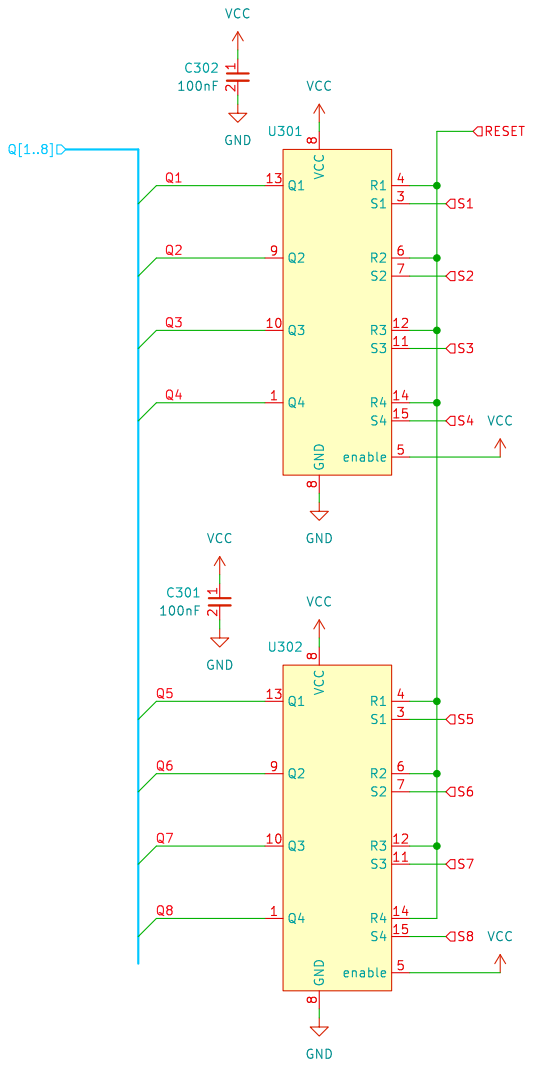
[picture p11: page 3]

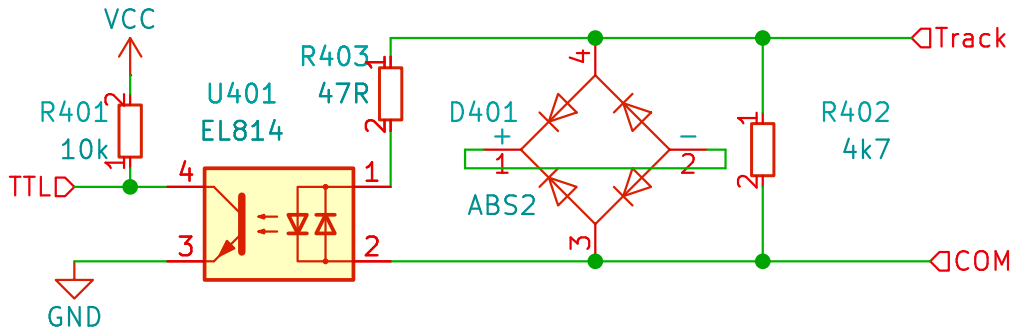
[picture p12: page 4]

Id: 4/21 Title: File: current sensor.kicad_sch Sheet: /CS2/

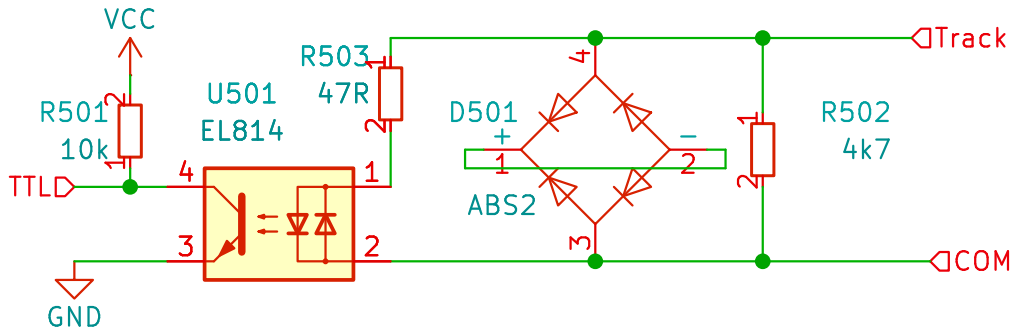
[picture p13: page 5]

Id: 5/21 Title: File: current sensor.kicad_sch Sheet: /CS3/

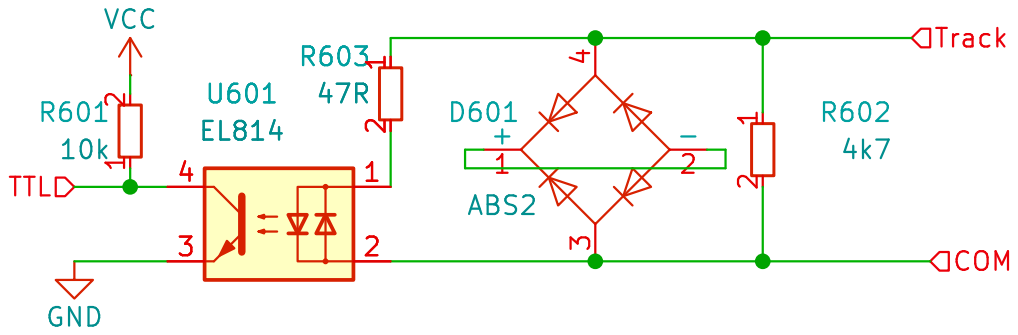
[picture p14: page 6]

Id: 6/21 Title: File: current sensor.kicad_sch Sheet: /CS4/

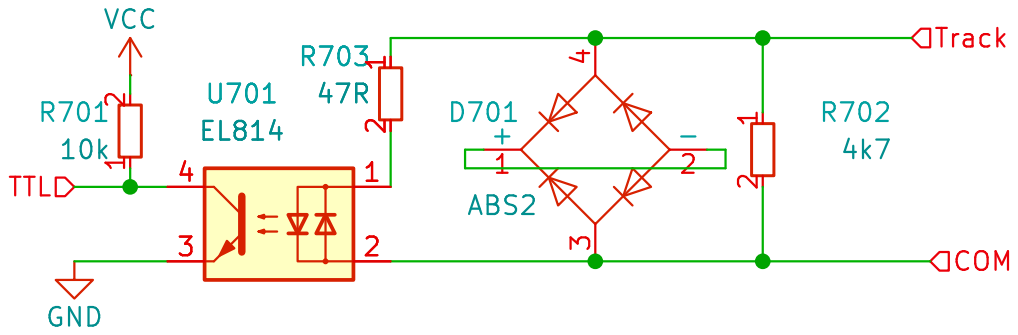
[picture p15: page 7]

Id: 7/21 Title: File: current sensor.kicad_sch Sheet: /CS5/

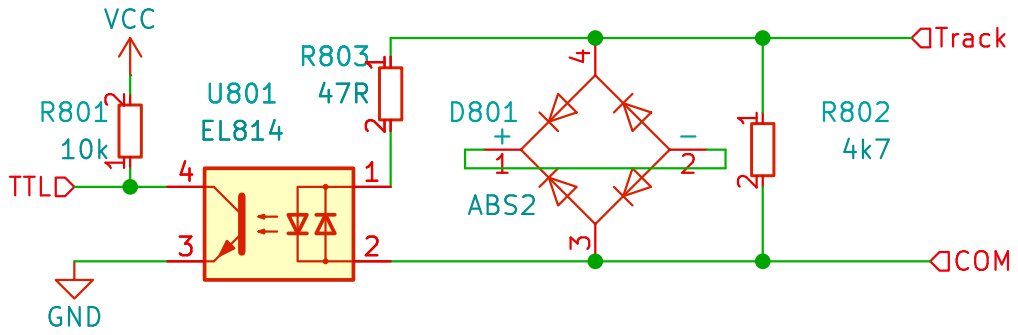
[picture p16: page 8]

Id: 8/21 Title: File: current sensor.kicad_sch Sheet: /CS6/

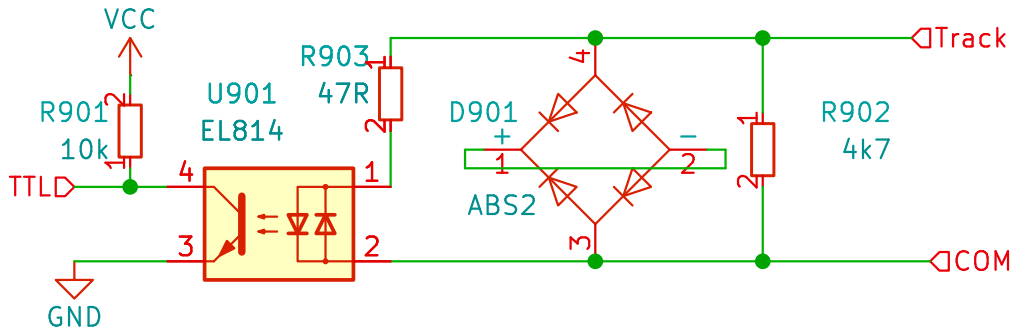
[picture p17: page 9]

Id: 9/21 Title: File: current sensor.kicad_sch Sheet: /CS7/

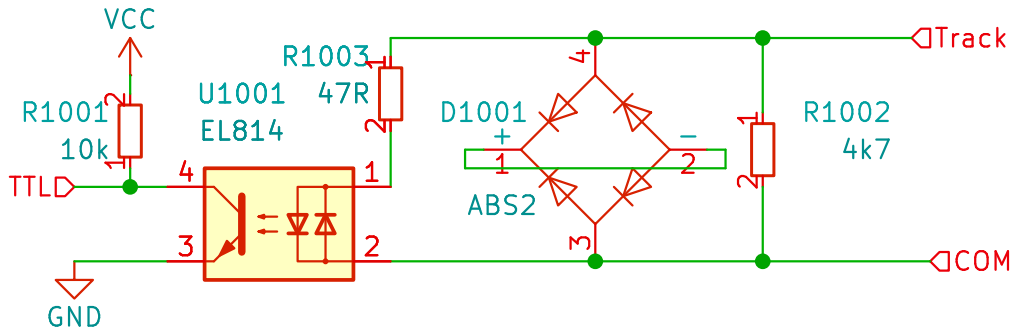
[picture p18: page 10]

Id: 10/21 Title: File: current sensor.kicad_sch Sheet: /CS8/

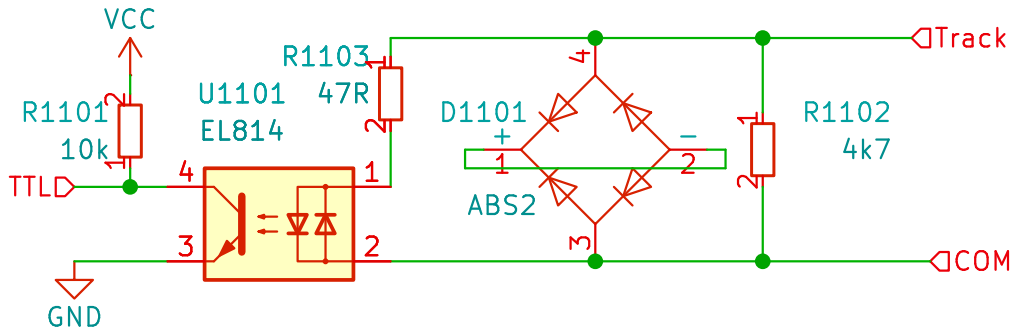
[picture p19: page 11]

Id: 11/21 Title: File: current sensor.kicad_sch Sheet: /CS9/

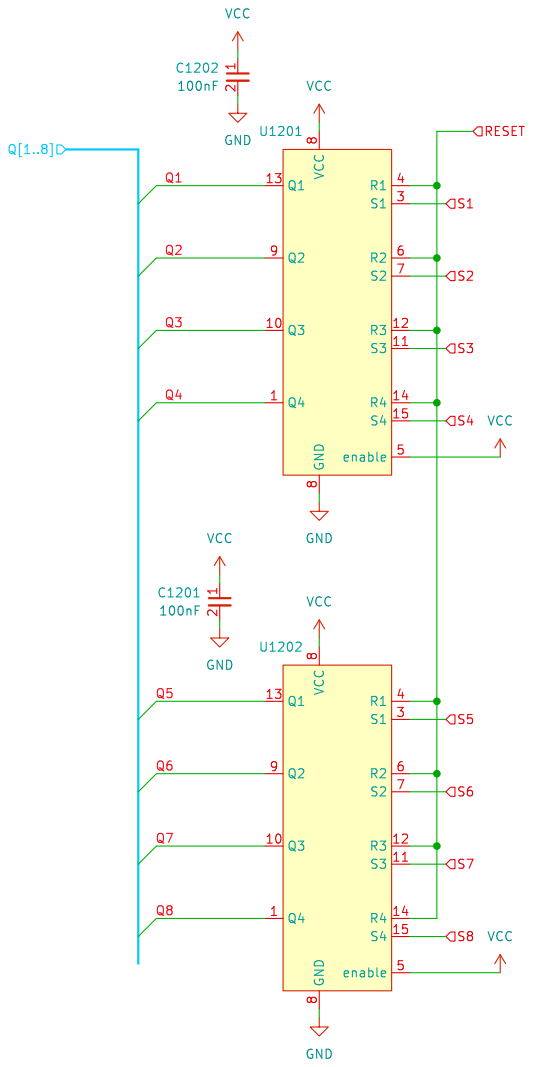
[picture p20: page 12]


Id: 13/21 Title: File: current sensor.kicad_sch Sheet: /CS10/


Id: 14/21 Title: File: current sensor.kicad_sch Sheet: /CS11/


Id: 15/21 Title: File: current sensor.kicad_sch Sheet: /CS12/


Id: 16/21 Title: File: current sensor.kicad_sch Sheet: /CS13/


Id: 17/21 Title: File: current sensor.kicad_sch Sheet: /CS14/


Id: 18/21 Title: File: current sensor.kicad_sch Sheet: /CS15/


Id: 19/21 Title: File: current sensor.kicad_sch Sheet: /CS16/


Id: 20/21 Title: File: shiftRegister.kicad_sch Sheet: /shiftRegister/ GND


Id: 21/21 Title: File: RJ45.kicad_sch Sheet: /RJ45/ GND 12345678

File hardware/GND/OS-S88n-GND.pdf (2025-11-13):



Id: 2/21 Title: File: current sensor.kicad_sch Sheet: /CS1/


Id: 3/21 Title: File: SR latch.kicad_sch Sheet: /SR-latch1/ GND


Id: 4/21 Title: File: current sensor.kicad_sch Sheet: /CS2/


Id: 5/21 Title: File: current sensor.kicad_sch Sheet: /CS3/


Id: 6/21 Title: File: current sensor.kicad_sch Sheet: /CS4/


Id: 7/21 Title: File: current sensor.kicad_sch Sheet: /CS5/


Id: 8/21 Title: File: current sensor.kicad_sch Sheet: /CS6/


Id: 9/21 Title: File: current sensor.kicad_sch Sheet: /CS7/


Id: 10/21 Title: File: current sensor.kicad_sch Sheet: /CS8/


Id: 11/21 Title: File: current sensor.kicad_sch Sheet: /CS12/


Id: 12/21 Title: File: SR latch.kicad_sch Sheet: /SR-latch2/ GND 1 2 C1201


Id: 13/21 Title: File: current sensor.kicad_sch Sheet: /CS14/


Id: 14/21 Title: File: current sensor.kicad_sch Sheet: /CS13/


Id: 15/21 Title: File: current sensor.kicad_sch Sheet: /CS15/


Id: 16/21 Title: File: current sensor.kicad_sch Sheet: /CS16/


Id: 17/21 Title: File: current sensor.kicad_sch Sheet: /CS10/


Id: 18/21 Title: File: current sensor.kicad_sch Sheet: /CS11/


Id: 19/21 Title: File: current sensor.kicad_sch Sheet: /CS9/


Id: 20/21 Title: File: shiftRegister.kicad_sch Sheet: /shiftRegister/ GND


Id: 21/21 Title: File: RJ45.kicad_sch Sheet: /RJ45/ GND 12345678

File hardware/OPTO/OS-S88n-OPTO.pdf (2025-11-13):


Id: 1/21 Title: File: OS-S88n-OPTO.kicad_sch Sheet: /


Id: 2/21 Title: File: current sensor.kicad_sch Sheet: /CS1/ GND



Id: 4/21 Title: File: current sensor.kicad_sch Sheet: /CS2/ GND


Id: 5/21 Title: File: current sensor.kicad_sch Sheet: /CS3/ GND


Id: 6/21 Title: File: current sensor.kicad_sch Sheet: /CS4/ GND


Id: 7/21 Title: File: current sensor.kicad_sch Sheet: /CS5/ GND


Id: 8/21 Title: File: current sensor.kicad_sch Sheet: /CS6/ GND


Id: 9/21 Title: File: current sensor.kicad_sch Sheet: /CS7/ GND


Id: 10/21 Title: File: current sensor.kicad_sch Sheet: /CS8/ GND


Id: 11/21 Title: File: current sensor.kicad_sch Sheet: /CS9/ GND



Id: 13/21 Title: File: current sensor.kicad_sch Sheet: /CS10/ GND


Id: 14/21 Title: File: current sensor.kicad_sch Sheet: /CS11/ GND


Id: 15/21 Title: File: current sensor.kicad_sch Sheet: /CS12/ GND


Id: 16/21 Title: File: current sensor.kicad_sch Sheet: /CS13/ GND


Id: 17/21 Title: File: current sensor.kicad_sch Sheet: /CS14/ GND


Id: 18/21 Title: File: current sensor.kicad_sch Sheet: /CS15/ GND


Id: 19/21 Title: File: current sensor.kicad_sch Sheet: /CS16/ GND


Id: 20/21 Title: File: shiftRegister.kicad_sch Sheet: /shiftRegister/ GND


Id: 21/21 Title: File: RJ45.kicad_sch Sheet: /RJ45/ GND 12345678

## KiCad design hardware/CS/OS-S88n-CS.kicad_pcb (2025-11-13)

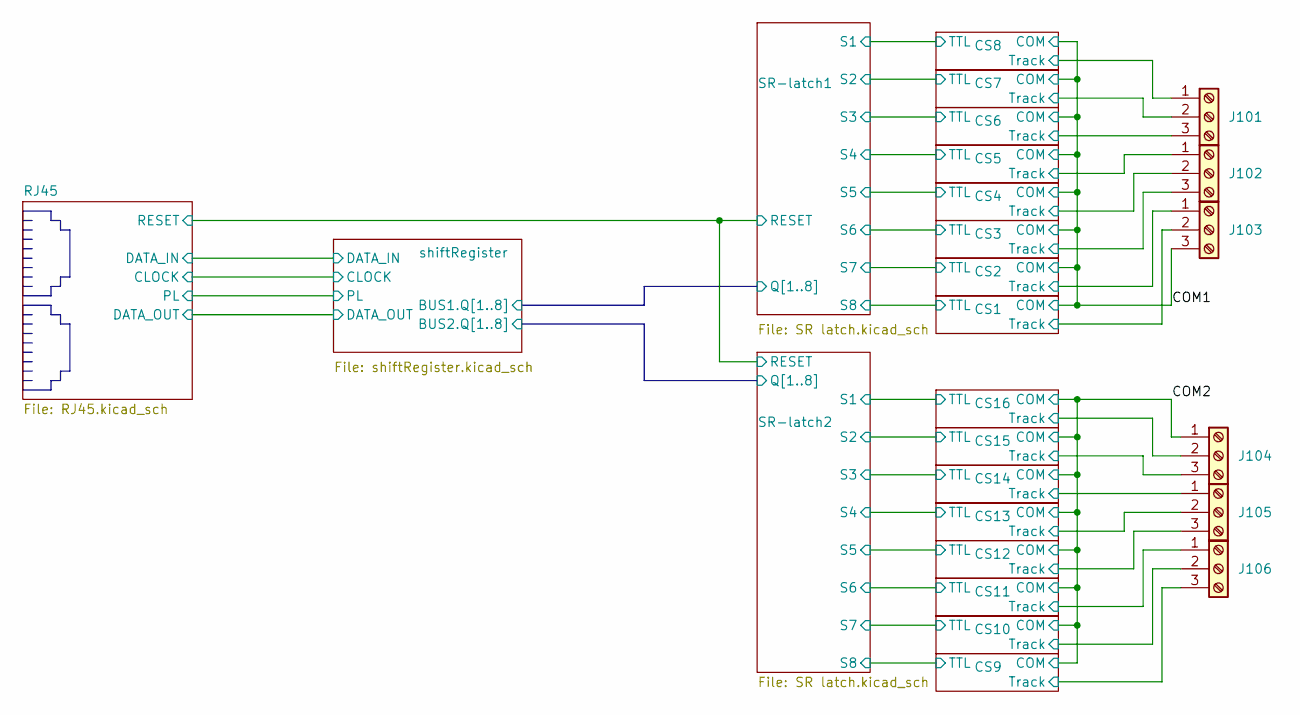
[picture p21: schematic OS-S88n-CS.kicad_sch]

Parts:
J101, J102, J103, J104, J105, J106: Screw_Terminal_01x03; TerminalBlock_Phoenix_MKDS-1,5-3-5.08_1x03_P5.08mm_Horizont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; JLCPCB Part# C557666

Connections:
/COM1: J103.3; also elsewhere on the board
/COM2: J104.1; also elsewhere on the board
/CS1/Track: J103.2; also elsewhere on the board
/CS2/Track: J103.1; also elsewhere on the board
/CS3/Track: J102.3; also elsewhere on the board
/CS4/Track: J102.2; also elsewhere on the board
/CS5/Track: J102.1; also elsewhere on the board
/CS6/Track: J101.3; also elsewhere on the board
/CS7/Track: J101.2; also elsewhere on the board
/CS8/Track: J101.1; also elsewhere on the board
/CS9/Track: J106.3; also elsewhere on the board
/CS10/Track: J106.2; also elsewhere on the board
/CS11/Track: J106.1; also elsewhere on the board
/CS12/Track: J105.3; also elsewhere on the board
/CS13/Track: J105.2; also elsewhere on the board
/CS14/Track: J105.1; also elsewhere on the board
/CS15/Track: J104.3; also elsewhere on the board
/CS16/Track: J104.2; also elsewhere on the board

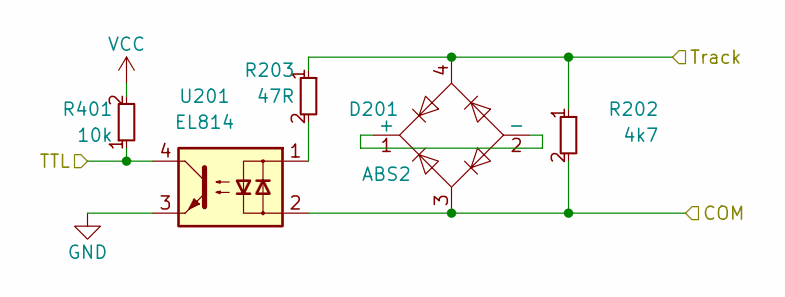
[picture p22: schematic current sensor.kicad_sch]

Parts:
D201: ABS2; Diode_Bridge_Diotec_ABS; JLCPCB Part# C123897
R202: 4k7; R_0603_smalltext; JLCPCB Part# C23162
R203: 47R; R_0603_smalltext; JLCPCB Part# C23182
R401: 10k; R_0603_smalltext; JLCPCB Part# C25804
U201: EL814; SMDIP-4_W9.53mm; JLCPCB Part# C500388

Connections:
/COM1: D201.3, R202.2, U201.2; also elsewhere on the board
/CS1/Track: D201.4, R202.1, R203.1; also elsewhere on the board
unnamed: D201.1 (+), D201.2 (-)
unnamed: R203.2, U201.1

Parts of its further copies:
D401, D501, D601, D701, D801, D901, D1001, D1101, D1301, D1401, D1501, D1601, D1701, D1801, D1901: ABS2; Diode_Bridge_Diotec_ABS; JLCPCB Part# C123897
R201, R501, R601, R701, R801, R901, R1001, R1101, R1301, R1401, R1501, R1601, R1701, R1801, R1901: 10k; R_0603_smalltext; JLCPCB Part# C25804
R402, R502, R602, R702, R802, R902, R1002, R1102, R1302, R1402, R1502, R1602, R1702, R1802, R1902: 4k7; R_0603_smalltext; JLCPCB Part# C23162
R403, R503, R603, R703, R803, R903, R1003, R1103, R1303, R1403, R1503, R1603, R1703, R1803, R1903: 47R; R_0603_smalltext; JLCPCB Part# C23182
U401, U501, U601, U701, U801, U901, U1001, U1101, U1301, U1401, U1501, U1601, U1701, U1801, U1901: EL814; SMDIP-4_W9.53mm; JLCPCB Part# C500388

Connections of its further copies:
/COM1: D401.3, D501.3, D601.3, D701.3, D801.3, D901.3, D1001.3, R402.2, R502.2, R602.2, R702.2, R802.2, R902.2, R1002.2, U401.2, U501.2, U601.2, U701.2, U801.2, U901.2, U1001.2; also elsewhere on the board
/COM2: D1101.3, D1301.3, D1401.3, D1501.3, D1601.3, D1701.3, D1801.3, D1901.3, R1102.2, R1302.2, R1402.2, R1502.2, R1602.2, R1702.2, R1802.2, R1902.2, U1101.2, U1301.2, U1401.2, U1501.2, U1601.2, U1701.2, U1801.2, U1901.2; also elsewhere on the board
/CS2/Track: D401.4, R402.1, R403.1; also elsewhere on the board
/CS3/TTL: R501.1, U501.4; also elsewhere on the board
/CS3/Track: D501.4, R502.1, R503.1; also elsewhere on the board
/CS4/TTL: R601.1, U601.4; also elsewhere on the board
/CS4/Track: D601.4, R602.1, R603.1; also elsewhere on the board
/CS5/TTL: R701.1, U701.4; also elsewhere on the board
/CS5/Track: D701.4, R702.1, R703.1; also elsewhere on the board
/CS6/TTL: R801.1, U801.4; also elsewhere on the board
/CS6/Track: D801.4, R802.1, R803.1; also elsewhere on the board
/CS7/TTL: R901.1, U901.4; also elsewhere on the board
/CS7/Track: D901.4, R902.1, R903.1; also elsewhere on the board
/CS8/TTL: R1001.1, U1001.4; also elsewhere on the board
/CS8/Track: D1001.4, R1002.1, R1003.1; also elsewhere on the board
/CS9/TTL: R1101.1, U1101.4; also elsewhere on the board
/CS9/Track: D1101.4, R1102.1, R1103.1; also elsewhere on the board
/CS10/TTL: R1301.1, U1301.4; also elsewhere on the board
/CS10/Track: D1301.4, R1302.1, R1303.1; also elsewhere on the board
/CS11/TTL: R1401.1, U1401.4; also elsewhere on the board
/CS11/Track: D1401.4, R1402.1, R1403.1; also elsewhere on the board
/CS12/TTL: R1501.1, U1501.4; also elsewhere on the board
/CS12/Track: D1501.4, R1502.1, R1503.1; also elsewhere on the board
/CS13/TTL: R1601.1, U1601.4; also elsewhere on the board
/CS13/Track: D1601.4, R1602.1, R1603.1; also elsewhere on the board
/CS14/TTL: R1701.1, U1701.4; also elsewhere on the board
/CS14/Track: D1701.4, R1702.1, R1703.1; also elsewhere on the board
/CS15/TTL: R1801.1, U1801.4; also elsewhere on the board
/CS15/Track: D1801.4, R1802.1, R1803.1; also elsewhere on the board
/CS16/TTL: R1901.1, U1901.4; also elsewhere on the board
/CS16/Track: D1901.4, R1902.1, R1903.1; also elsewhere on the board
unnamed: D401.1 (+), D401.2 (-)
unnamed: D501.1 (+), D501.2 (-)
unnamed: D601.1 (+), D601.2 (-)
unnamed: D701.1 (+), D701.2 (-)
unnamed: D801.1 (+), D801.2 (-)
unnamed: D901.1 (+), D901.2 (-)
unnamed: D1001.1 (+), D1001.2 (-)
unnamed: D1101.1 (+), D1101.2 (-)
unnamed: D1301.1 (+), D1301.2 (-)
unnamed: D1401.1 (+), D1401.2 (-)
unnamed: D1501.1 (+), D1501.2 (-)
unnamed: D1601.1 (+), D1601.2 (-)
unnamed: D1701.1 (+), D1701.2 (-)
unnamed: D1801.1 (+), D1801.2 (-)
unnamed: D1901.1 (+), D1901.2 (-)
unnamed: R403.2, U401.1
unnamed: R503.2, U501.1
unnamed: R603.2, U601.1
unnamed: R703.2, U701.1
unnamed: R803.2, U801.1
unnamed: R903.2, U901.1
unnamed: R1003.2, U1001.1
unnamed: R1103.2, U1101.1
unnamed: R1303.2, U1301.1
unnamed: R1403.2, U1401.1
unnamed: R1503.2, U1501.1
unnamed: R1603.2, U1601.1
unnamed: R1703.2, U1701.1
unnamed: R1803.2, U1801.1
unnamed: R1903.2, U1901.1

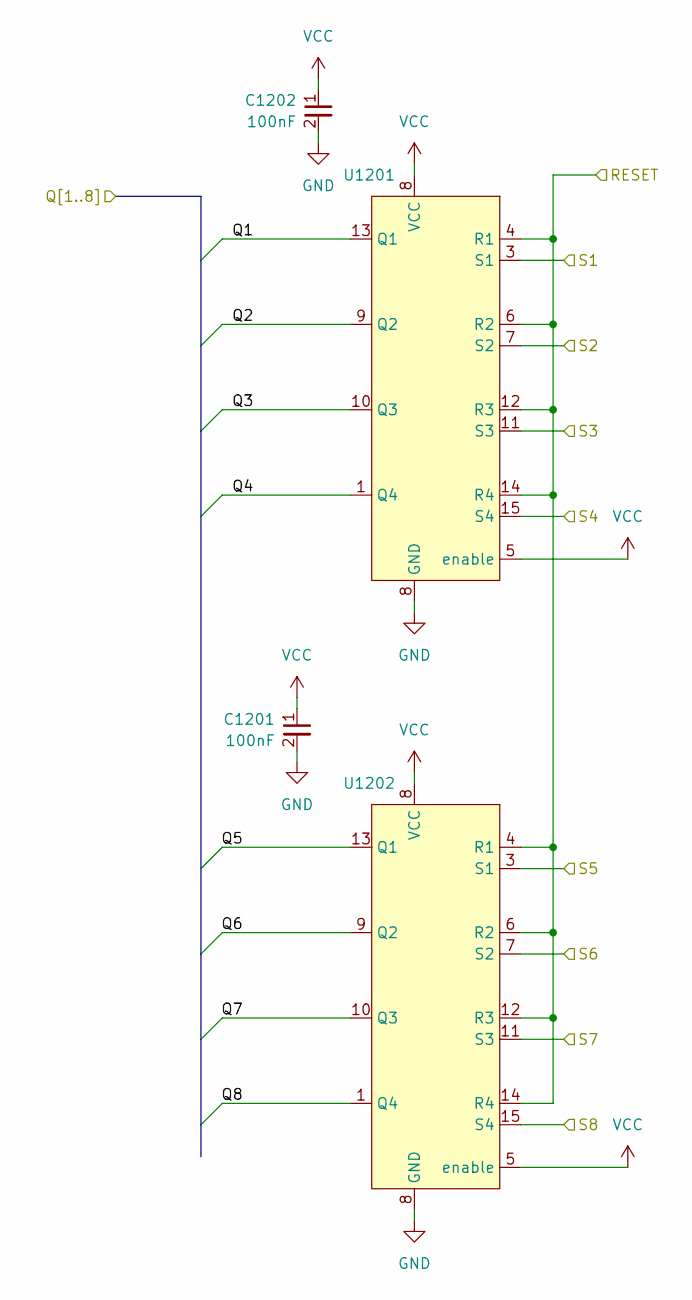
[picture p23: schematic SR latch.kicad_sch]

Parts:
C1201, C1202: 100nF; C_0402_1005Metric; JLCPCB Part# C307331
U1201, U1202: SOIC-16_3.9x9.9mm_P1.27mm; JLCPCB Part# C133986

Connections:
/CS9/TTL: U1202.15 (S4); also elsewhere on the board
/CS10/TTL: U1202.11 (S3); also elsewhere on the board
/CS11/TTL: U1202.7 (S2); also elsewhere on the board
/CS12/TTL: U1202.3 (S1); also elsewhere on the board
/CS13/TTL: U1201.15 (S4); also elsewhere on the board
/CS14/TTL: U1201.11 (S3); also elsewhere on the board
/CS15/TTL: U1201.7 (S2); also elsewhere on the board
/CS16/TTL: U1201.3 (S1); also elsewhere on the board
/RJ45/RESET: U1201.4 (R1), U1201.6 (R2), U1201.12 (R3), U1201.14 (R4), U1202.4 (R1), U1202.6 (R2), U1202.12 (R3), U1202.14 (R4); also elsewhere on the board
/SR-latch2/Q1: U1201.13 (Q1); also elsewhere on the board
/SR-latch2/Q2: U1201.9 (Q2); also elsewhere on the board
/SR-latch2/Q3: U1201.10 (Q3); also elsewhere on the board
/SR-latch2/Q4: U1201.1 (Q4); also elsewhere on the board
/SR-latch2/Q5: U1202.13 (Q1); also elsewhere on the board
/SR-latch2/Q6: U1202.9 (Q2); also elsewhere on the board
/SR-latch2/Q7: U1202.10 (Q3); also elsewhere on the board
/SR-latch2/Q8: U1202.1 (Q4); also elsewhere on the board

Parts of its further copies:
C301, C302: 100nF; C_0402_1005Metric; JLCPCB Part# C307331
U301, U302: SOIC-16_3.9x9.9mm_P1.27mm; JLCPCB Part# C133986

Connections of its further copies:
/CS3/TTL: U302.7 (S2); also elsewhere on the board
/CS4/TTL: U302.3 (S1); also elsewhere on the board
/CS5/TTL: U301.15 (S4); also elsewhere on the board
/CS6/TTL: U301.11 (S3); also elsewhere on the board
/CS7/TTL: U301.7 (S2); also elsewhere on the board
/CS8/TTL: U301.3 (S1); also elsewhere on the board
/RJ45/RESET: U301.4 (R1), U301.6 (R2), U301.12 (R3), U301.14 (R4), U302.4 (R1), U302.6 (R2), U302.12 (R3), U302.14 (R4); also elsewhere on the board
/SR-latch1/Q1: U301.13 (Q1); also elsewhere on the board
/SR-latch1/Q2: U301.9 (Q2); also elsewhere on the board
/SR-latch1/Q3: U301.10 (Q3); also elsewhere on the board
/SR-latch1/Q4: U301.1 (Q4); also elsewhere on the board
/SR-latch1/Q5: U302.13 (Q1); also elsewhere on the board
/SR-latch1/Q6: U302.9 (Q2); also elsewhere on the board
/SR-latch1/Q7: U302.10 (Q3); also elsewhere on the board
/SR-latch1/Q8: U302.1 (Q4); also elsewhere on the board

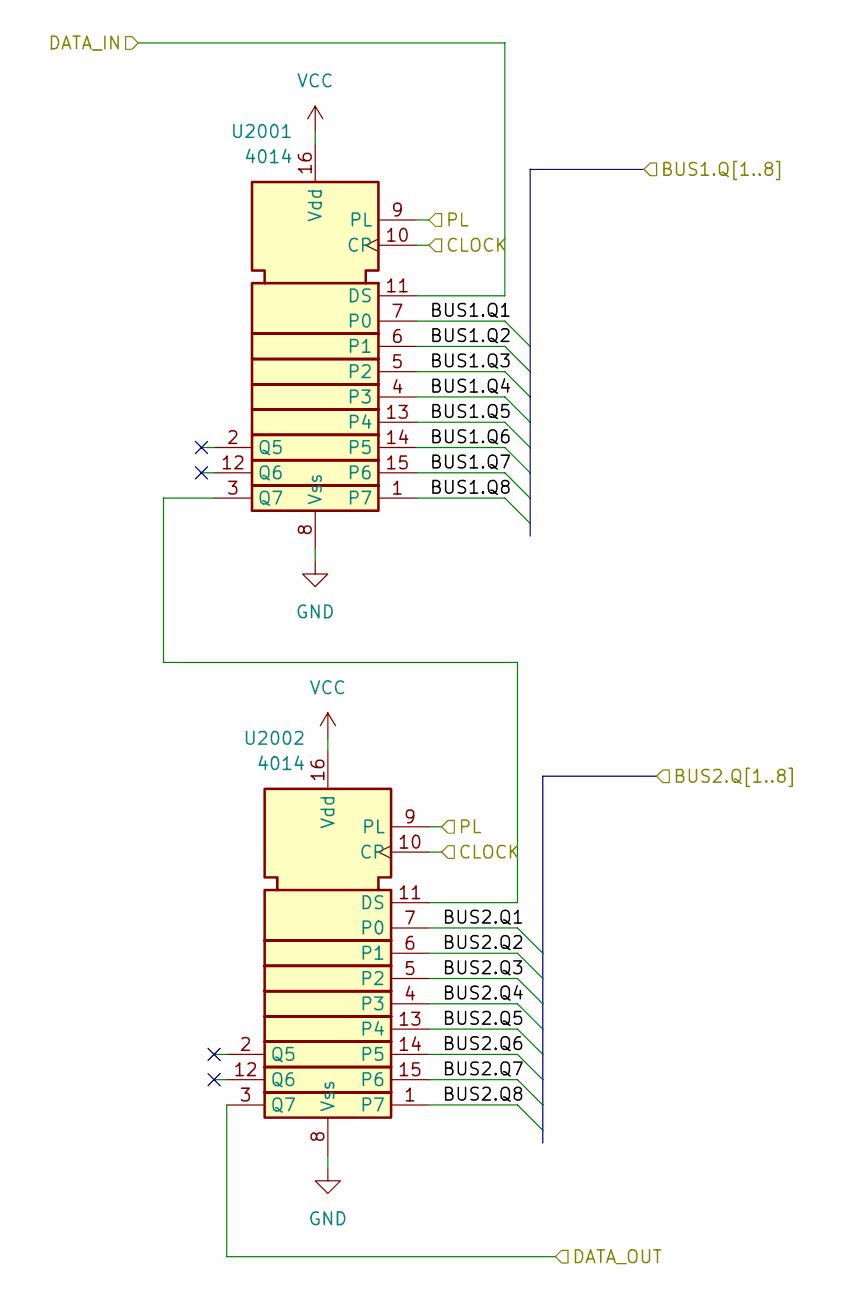
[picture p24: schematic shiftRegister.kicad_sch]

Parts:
U2001, U2002: 4014; SOIC-16_3.9x9.9mm_P1.27mm; JLCPCB Part# C496106

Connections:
/RJ45/CLOCK: U2001.10 (CP), U2002.10 (CP); also elsewhere on the board
/RJ45/DATA_IN: U2001.11 (DS); also elsewhere on the board
/RJ45/DATA_OUT: U2002.3 (Q7); also elsewhere on the board
/RJ45/PL: U2001.9 (PL), U2002.9 (PL); also elsewhere on the board
/SR-latch1/Q1: U2001.7 (P0); also elsewhere on the board
/SR-latch1/Q2: U2001.6 (P1); also elsewhere on the board
/SR-latch1/Q3: U2001.5 (P2); also elsewhere on the board
/SR-latch1/Q4: U2001.4 (P3); also elsewhere on the board
/SR-latch1/Q5: U2001.13 (P4); also elsewhere on the board
/SR-latch1/Q6: U2001.14 (P5); also elsewhere on the board
/SR-latch1/Q7: U2001.15 (P6); also elsewhere on the board
/SR-latch1/Q8: U2001.1 (P7); also elsewhere on the board
/SR-latch2/Q1: U2002.7 (P0); also elsewhere on the board
/SR-latch2/Q2: U2002.6 (P1); also elsewhere on the board
/SR-latch2/Q3: U2002.5 (P2); also elsewhere on the board
/SR-latch2/Q4: U2002.4 (P3); also elsewhere on the board
/SR-latch2/Q5: U2002.13 (P4); also elsewhere on the board
/SR-latch2/Q6: U2002.14 (P5); also elsewhere on the board
/SR-latch2/Q7: U2002.15 (P6); also elsewhere on the board
/SR-latch2/Q8: U2002.1 (P7); also elsewhere on the board
unnamed: U2001.3 (Q7), U2002.11 (DS)

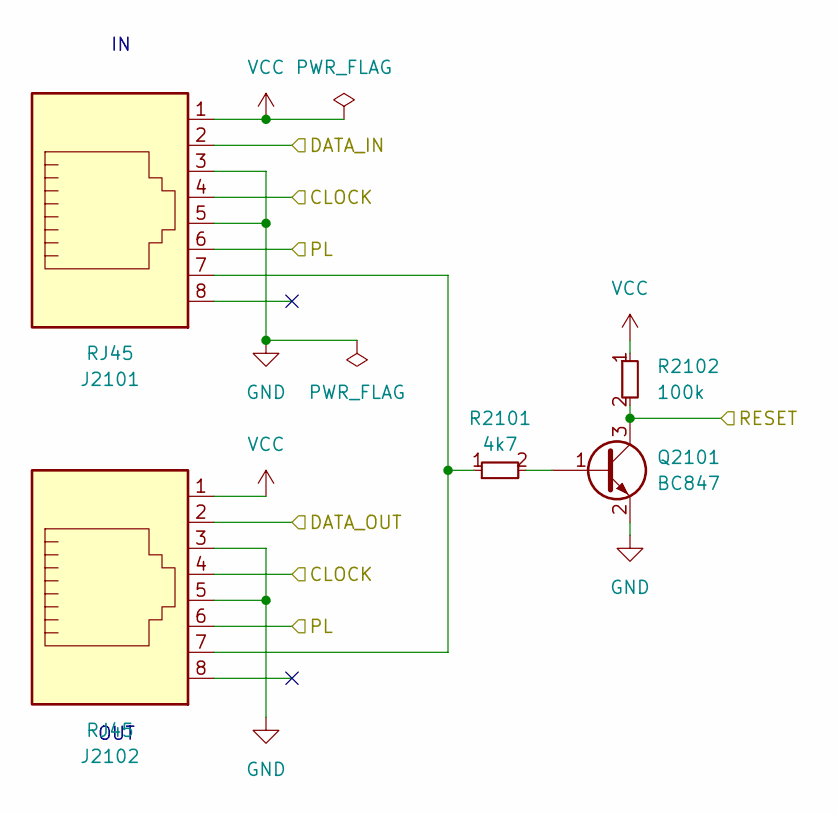
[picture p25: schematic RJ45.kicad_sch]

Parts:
J2101, J2102: RJ45; RJ45_Amphenol_54602-x08_Horizontal; JLCPCB Part# C2847314
Q2101: BC847; SOT-23; JLCPCB Part# C181140
R2101: 4k7; R_0603_smalltext; JLCPCB Part# C23162
R2102: 100k; R_0603_smalltext; JLCPCB Part# C25803

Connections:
/RJ45/CLOCK: J2101.4, J2102.4; also elsewhere on the board
/RJ45/DATA_IN: J2101.2; also elsewhere on the board
/RJ45/DATA_OUT: J2102.2; also elsewhere on the board
/RJ45/PL: J2101.6, J2102.6; also elsewhere on the board
/RJ45/RESET: Q2101.3 (C), R2102.2; also elsewhere on the board
unnamed: J2101.7, J2102.7, R2101.1
unnamed: Q2101.1 (B), R2101.2

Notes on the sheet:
OUT

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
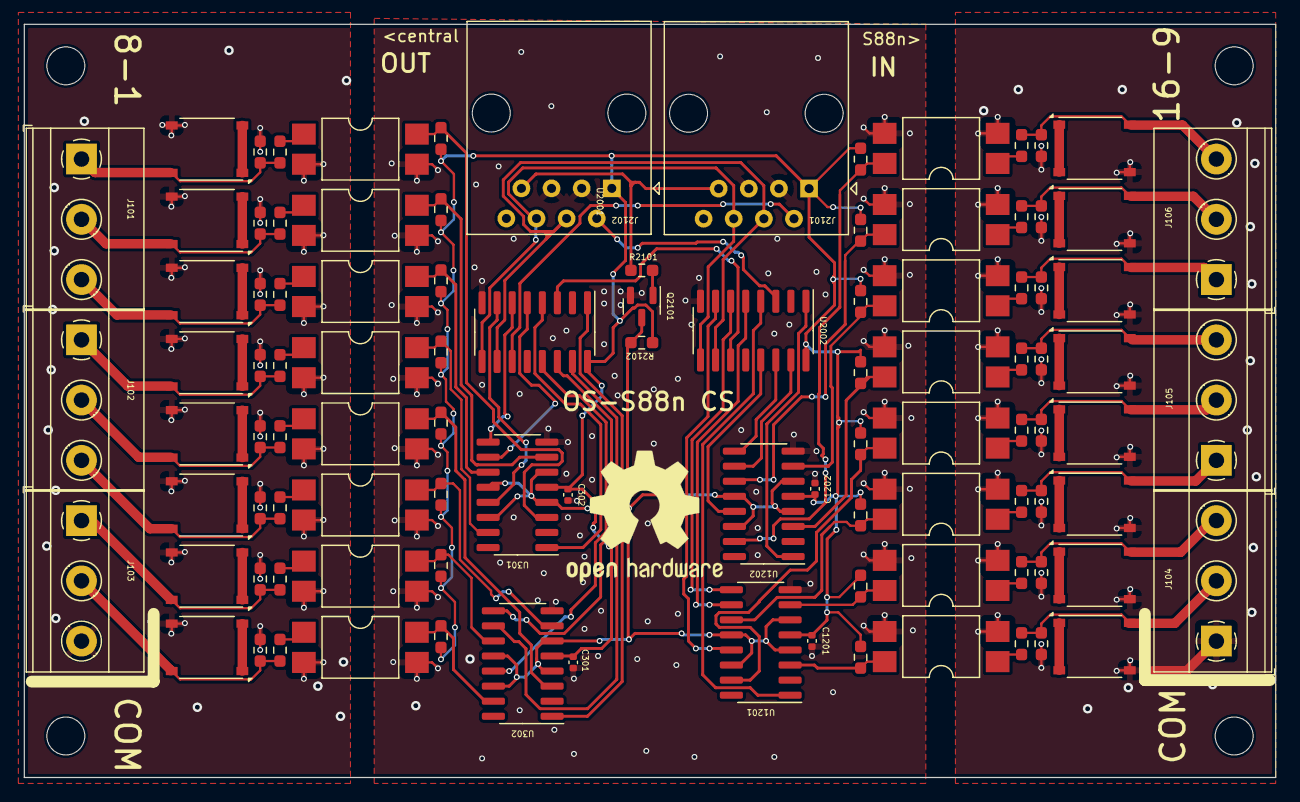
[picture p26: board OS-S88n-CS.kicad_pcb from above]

Board: 2 copper layers, 105.5 x 63.5 mm, 101 parts (0 on the bottom side), 92 nets.
